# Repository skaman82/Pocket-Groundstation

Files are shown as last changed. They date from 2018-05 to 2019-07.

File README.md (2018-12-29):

# Pocket-Groundstation
The Pocket-Groundstation is a mini ground station that will accept any Fatshark module.</br> 
<strong>Project updates</strong> > https://github.com/skaman82/Pocket-Groundstation/blob/master/updates.md

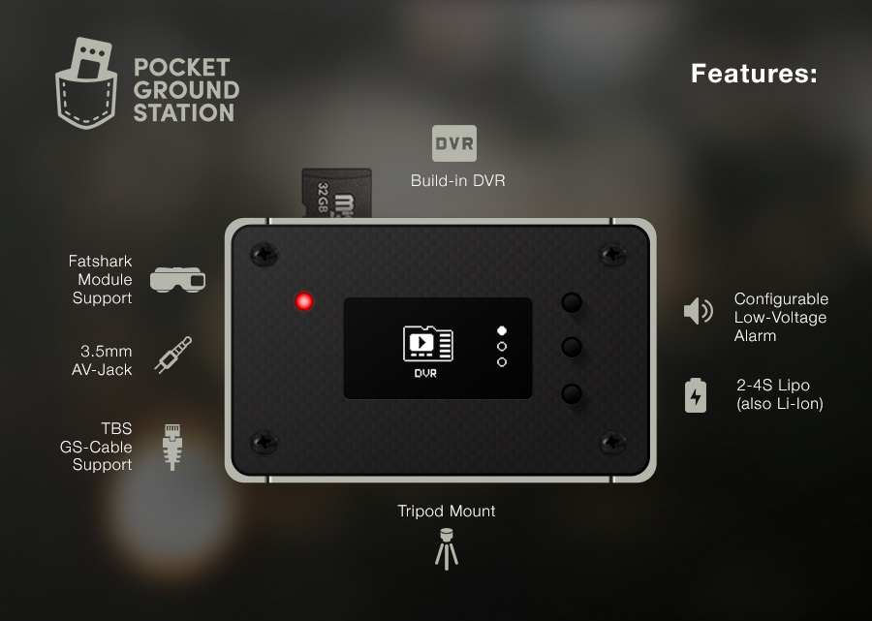
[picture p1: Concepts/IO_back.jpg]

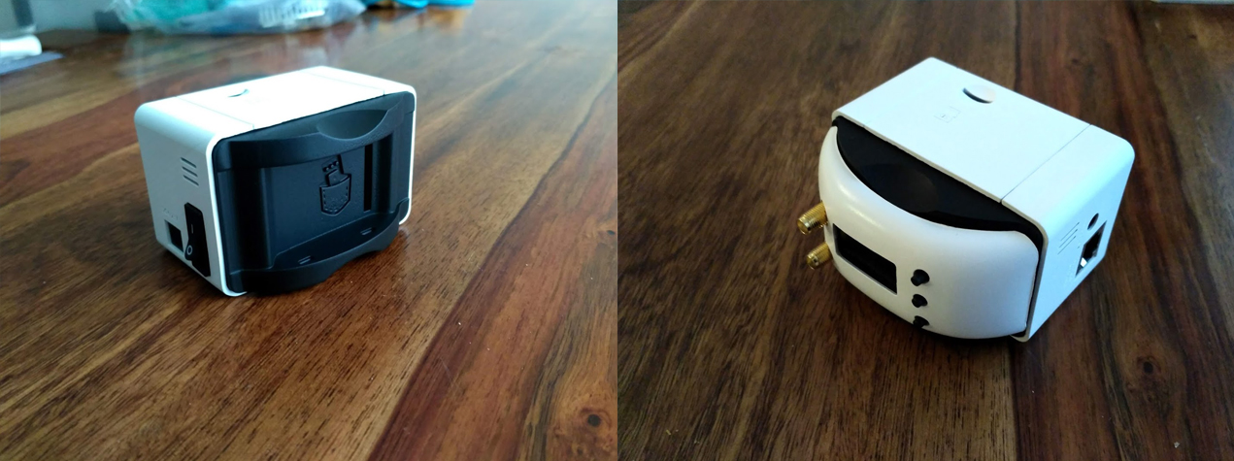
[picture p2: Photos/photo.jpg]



<b>Features:</b></br>
• takes 2S to 4S voltage</br>
• 3,5mm AV output</br>
• RJ45 output for power+AV (only one wire to goggles) - constant 8V output on any power source </br>
• Powerswitch</br>
• Build-in DVR</br>
• Automatical switching between DVR output (to adjust settings or review footage) or direct module output</br>
• Low-voltage alarm and cell autodetection (adjustable via OLED, so it can work with lipo or li-ion batteries)</br>
• DRV-control via OLED (Eachine Pro DVR)</br>
• RSSI/Channel-information and DVR-Autostart (only with True-D module with 3.7D firmware)</br>
</br>

If you want to join the project or contribute, you are very welcome to do so!</br></br>

<b>Parts:</b></br>
• 3D-Printed Parts </br>
or order them here: </br>
https://www.shapeways.com/product/CZG7FD8B4/pocketgroundstation-module-insert</br>
https://www.shapeways.com/product/DPKJJELEF/pocketgroundstation-case-side-cover</br>
https://www.shapeways.com/product/GCXG232QY/pocketgroundstation-case</br>
</br>
</br>
• PCBs (you can order them with the provided Gerber files in the PCB Folder at http://jlcpcb.com or other vendors) </br>
• M3 inserts (https://de.aliexpress.com/item/100-teile-los-messingeinsatz-M2-M2-5-M3-Durch-gewinde-messing-gewindebuchse-r-ndelmuttern-f-r/32840519444.html) </br>
• Tripod 1/4" Insert: (https://de.aliexpress.com/item/20Pcs-M3-M4-M5-M6-M8-Zinc-Plated-Carbon-Steel-Knurled-Nuts-Rivnut-Flat-Head-Threaded/32812028855.html)</br>
• Eachine PRO DVR </br>
• Arduino Pro Mini (https://de.aliexpress.com/item/1PCS-new-version-1pcs-ATMEGA328P-Pro-Mini-328-Mini-ATMEGA328-5V-16MHz-for-arduino/32830465958.html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)</br>
• 5V Buzzer</br>
• 3-35V to 1.2-30V Step up/down (https://de.aliexpress.com/item/DC-DC-Auto-Boost-Buck-Step-Up-Step-Down-Converter-Module-Solar-Voltage-LM2577-Module/32829391285.html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)</br>
• DC 5.5x2.5 PCB socket (https://de.aliexpress.com/item/10pcs-DC-005-Black-DC-Power-Jack-Socket-Connector-DC005-5-5-2-1mm-2-1/32361314769.html)</br>
• 3.5mm PCB socket (PJ-320D) (https://de.aliexpress.com/item/10pcs-lot-3-5-headphone-jack-audio-jack-PJ-320D-4-pin-SMD-MP3-Accessories-PJ320D/32439357849.html)</br>
• RJ45 PCB socket (RJ45 MOLEX 0446200002/RJ45 MOLEX 0446200001)</br>
• I2C OLED Display 1.3" (https://de.aliexpress.com/item/1-3-Inch-1-3-White-OLED-LCD-4PIN-Display-Module-IIC-I2C-Interface-128x64-for/32837066822.html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)</br>
• PWM video switch (https://de.aliexpress.com/item/2015-Mini-2-Ways-Video-Switcher-Module-2-Channels-Video-Switch-Unit-for-FPV/32552115472.html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)</br>
• Diode (SMD S1A)</br>
• Resistors 1206 (4.7K / 18K / 220 Ohm)</br>
• Red 3mm LED</br>
• Tactile buttons (3x) (https://de.aliexpress.com/item/100-st-cke-6-6-7mm-Licht-touch-schalter-DIP4-ON-OFF-Tactile-Push-button-micro/32846526815.html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)</br>
• Power switch (https://de.aliexpress.com/item/10Pcs-AC-125V-12A-250V-10A-SPST-2-Pin-2-Position-Mini-Marine-Boat-Switches-Rocker/32830066263.html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)</br>
• 5V 2A BEC (Diatone)</br>
• RJ45 TBS Tango Cable </br>
• Optional: 3.5mm AV Cable</br>
• Optional: Capacitator (470uF 25V)</br>

# The Build
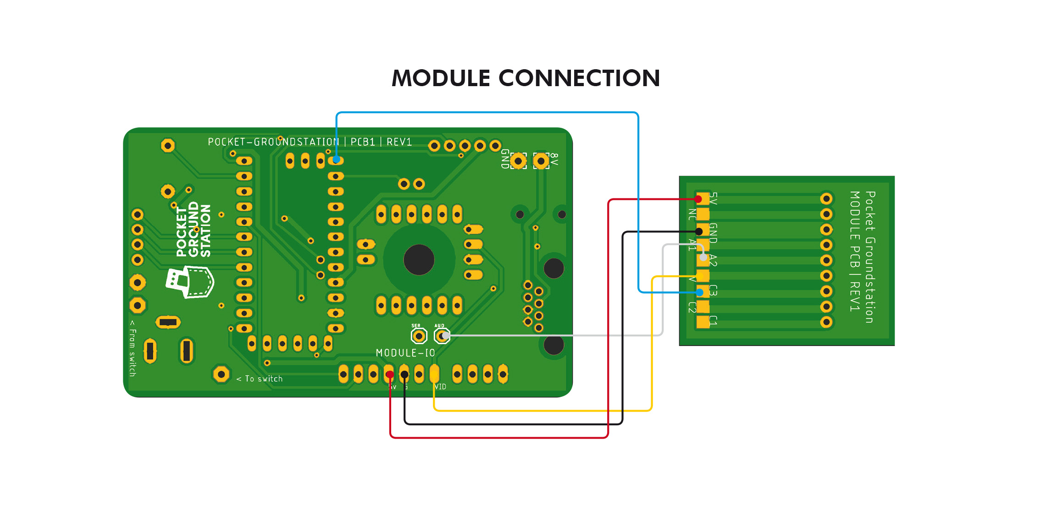
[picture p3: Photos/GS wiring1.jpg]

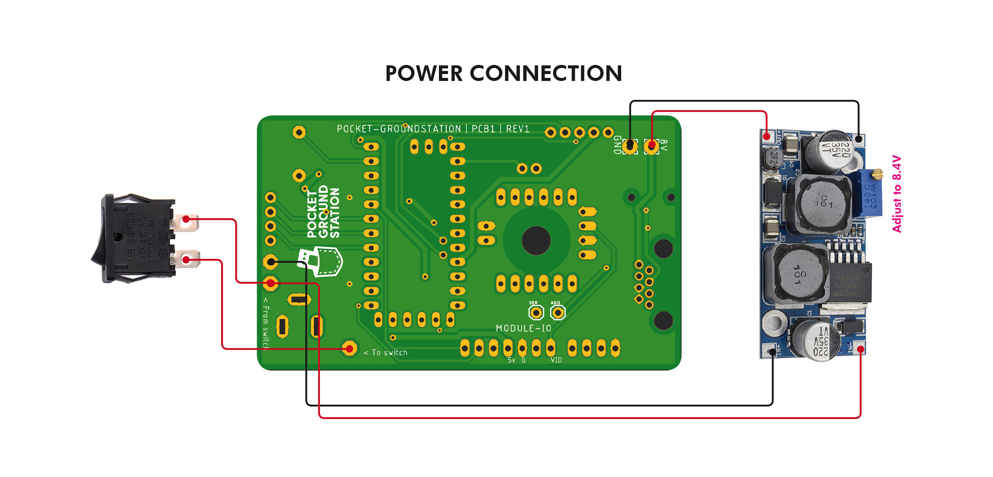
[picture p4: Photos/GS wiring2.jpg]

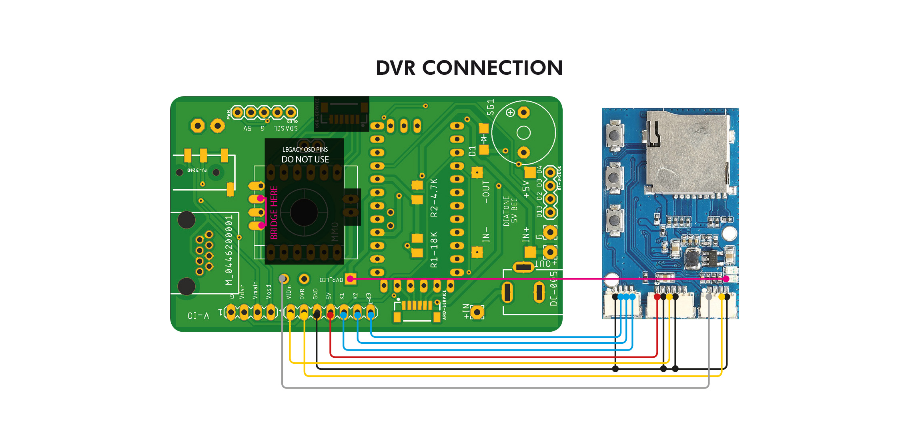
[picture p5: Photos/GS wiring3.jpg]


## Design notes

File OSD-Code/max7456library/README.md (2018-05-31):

# MAX7456
A library for interfacing with MAX7456 OSD chip originally created by people at http://theboredengineers.com/2012/12/a-max7456-library-for-arduino/.

This library should be compatible with Arduino IDE 1.6.6.

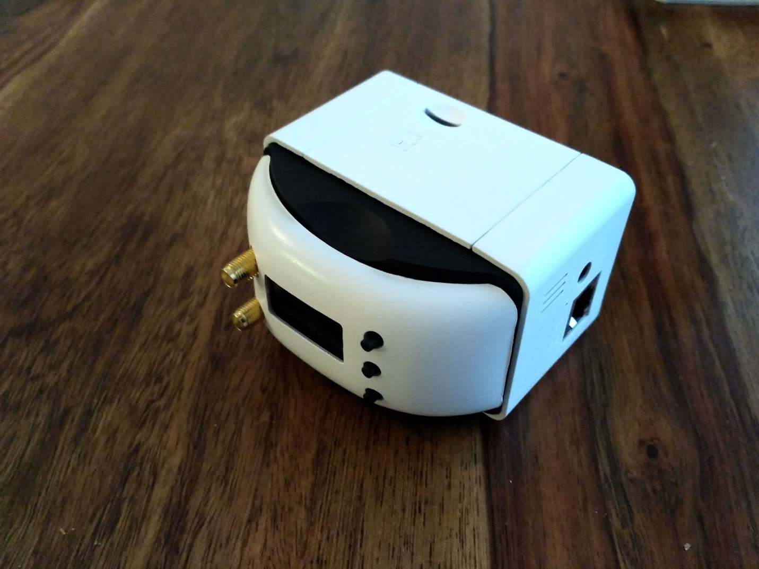
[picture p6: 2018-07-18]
Photos/IMG_20180714_202903_HDR.jpg

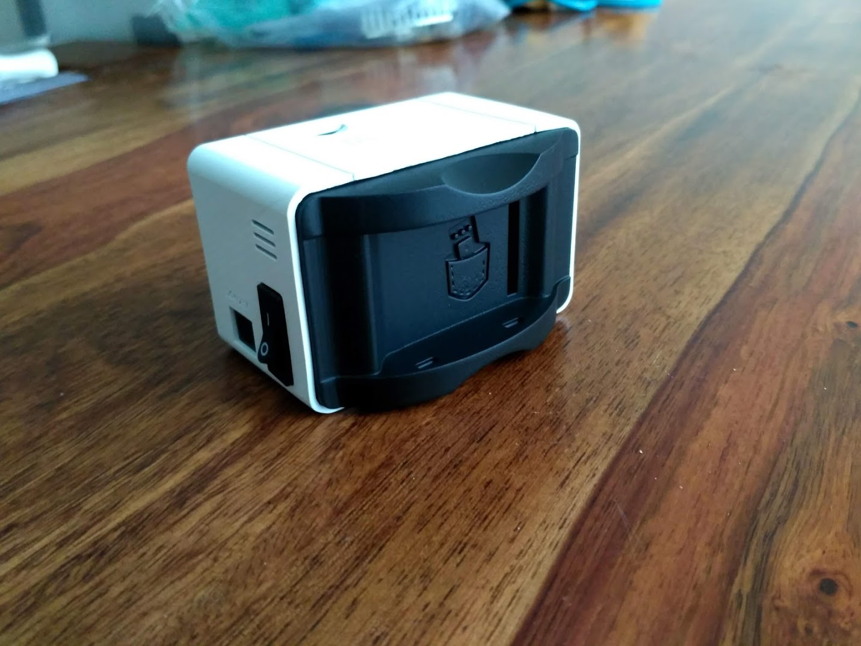
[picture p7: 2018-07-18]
Photos/IMG_20180714_121051_HDR.jpg

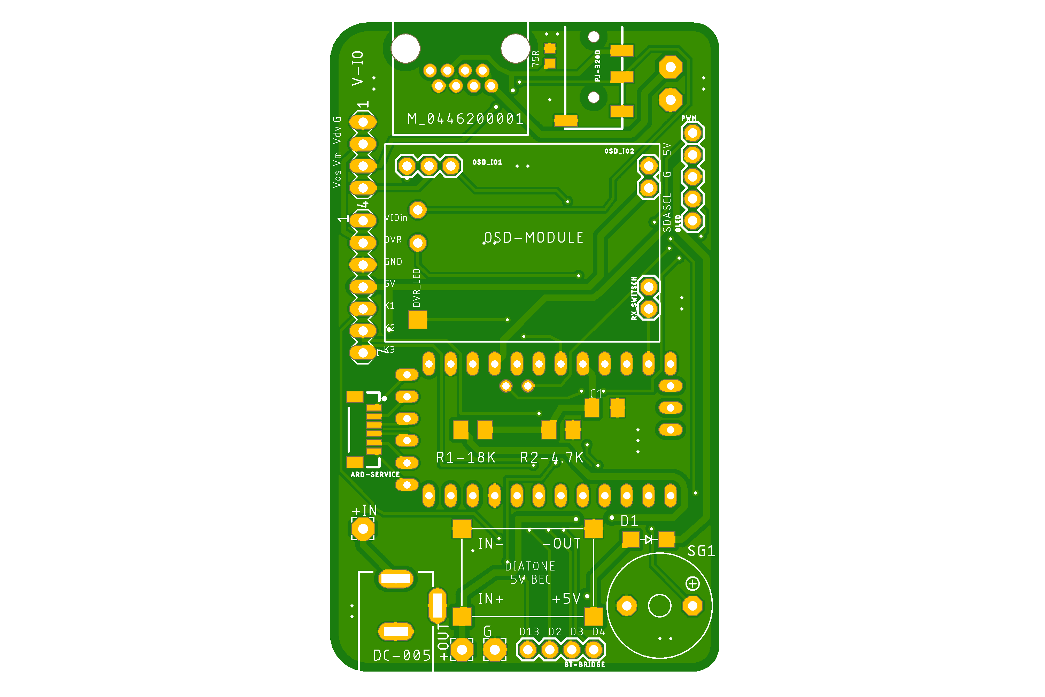
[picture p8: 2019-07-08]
PCB Files/Gerber Files/PCB 1_top.png

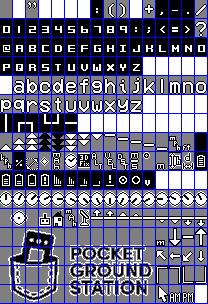
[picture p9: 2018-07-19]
OSD-Code/OSD fonts/pocketgroundstation-font.png

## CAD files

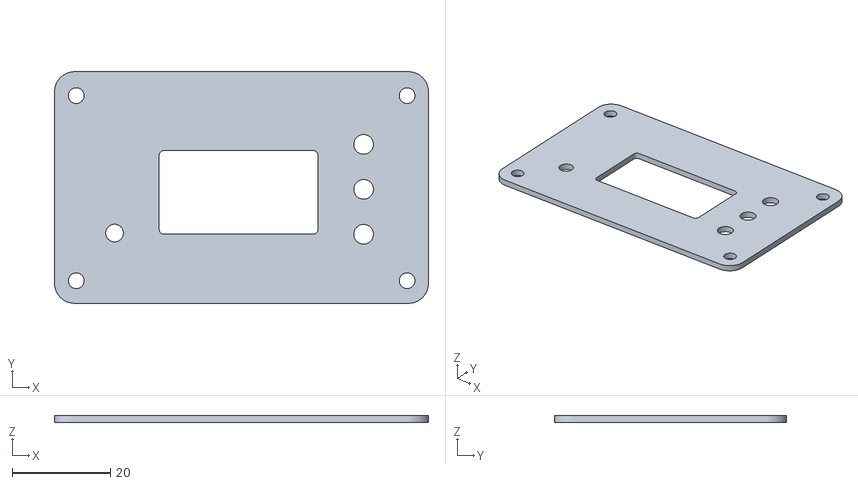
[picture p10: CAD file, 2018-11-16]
3D files/STLs/case cover plate 1,5mm_fixed.stl
76.0 x 47.1 x 1.50

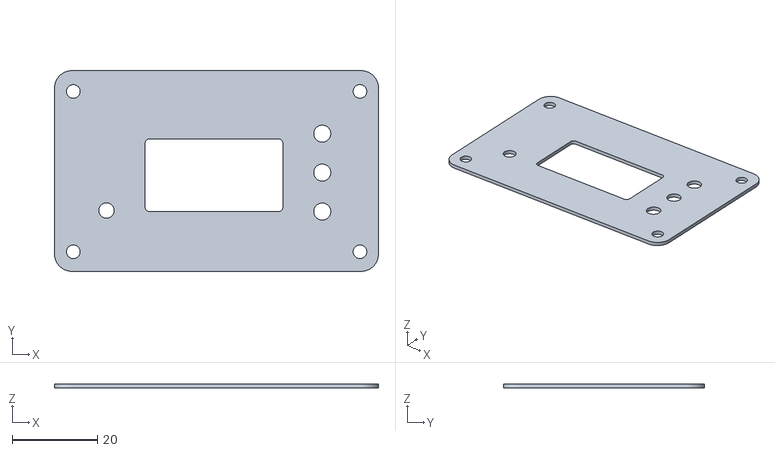
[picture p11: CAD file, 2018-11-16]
3D files/STLs/case cover plate 1,0mm_fixed.stl
76.0 x 47.1 x 1.00

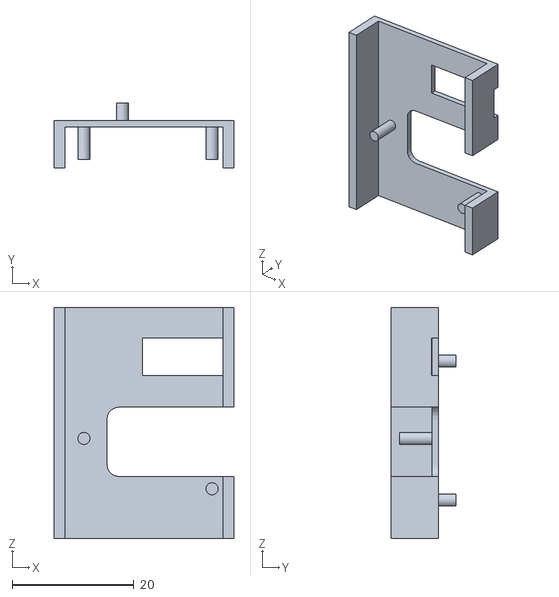
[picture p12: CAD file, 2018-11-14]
3D files/STLs/CE3_DVR adapter_scaled_fixed.stl
29.6 x 10.8 x 38.0

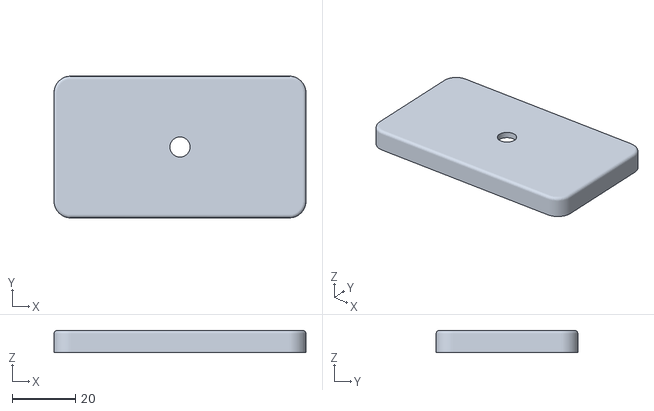
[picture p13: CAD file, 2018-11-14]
3D files/STLs/Magnet stand_fixed.stl
80.0 x 45.0 x 7.00

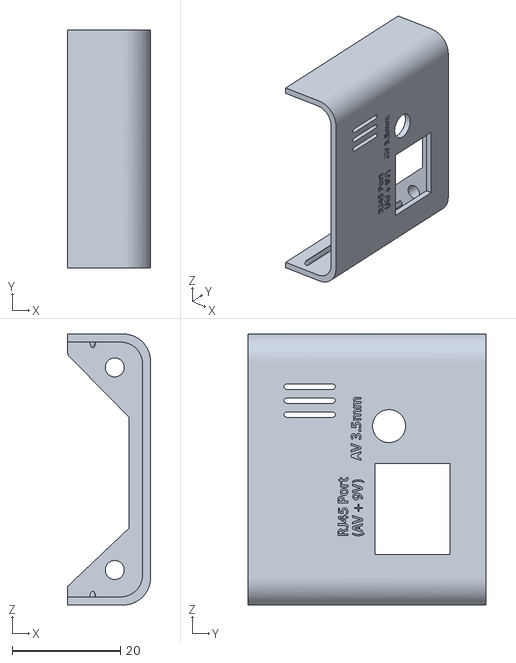
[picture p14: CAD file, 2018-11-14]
3D files/STLs/CE3_Side_left_scaled_fixed.stl
15.3 x 44.0 x 50.0

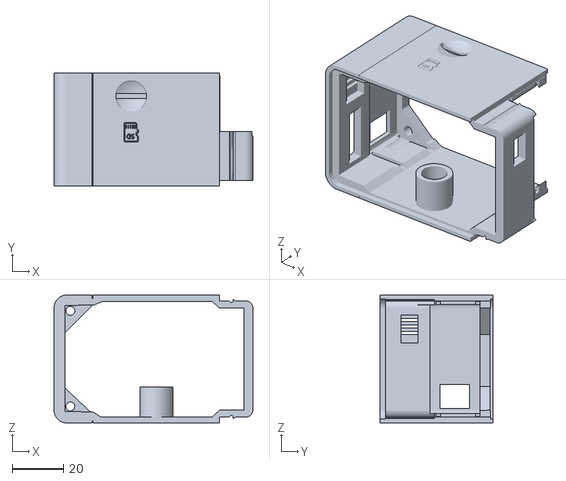
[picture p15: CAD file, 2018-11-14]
3D files/STLs/CE3_Case_scaled_fixed.stl
77.8 x 44.0 x 50.0

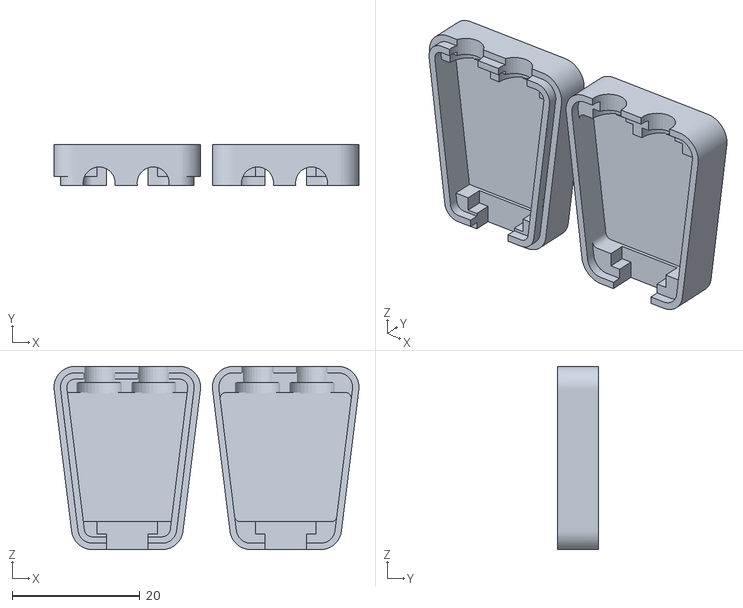
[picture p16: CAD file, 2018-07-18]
3D files/STLs/Cover_cable_fixed.stl
47.7 x 6.39 x 28.7

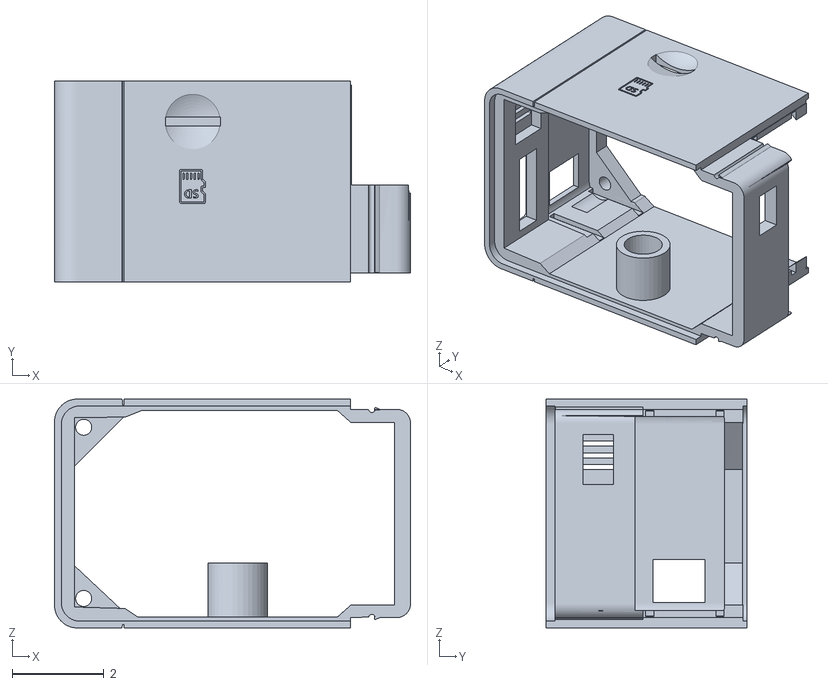
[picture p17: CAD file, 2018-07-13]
3D files/STLs/Case_fixed.stl
7.78 x 4.40 x 5.00

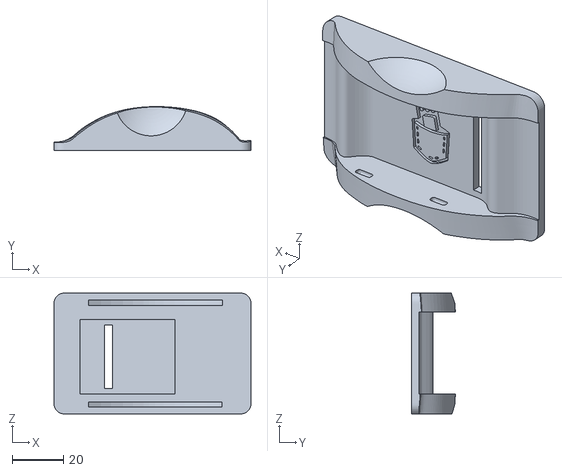
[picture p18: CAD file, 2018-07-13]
3D files/STLs/Module insert v3_fixed.stl
76.6 x 17.0 x 47.0

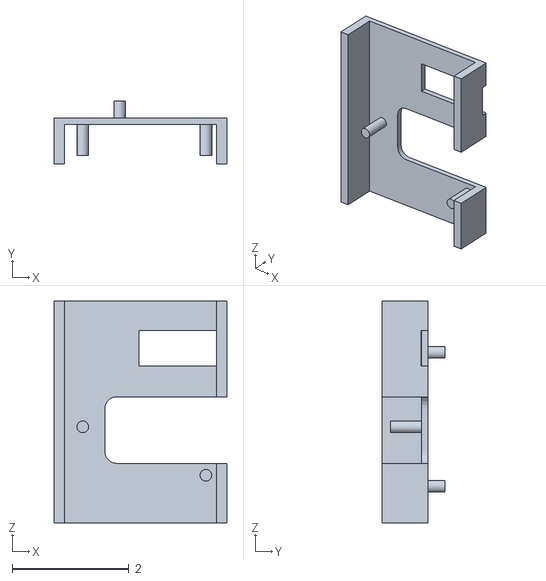
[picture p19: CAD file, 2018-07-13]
3D files/STLs/DVR adapter_fixed.stl
2.96 x 1.08 x 3.80

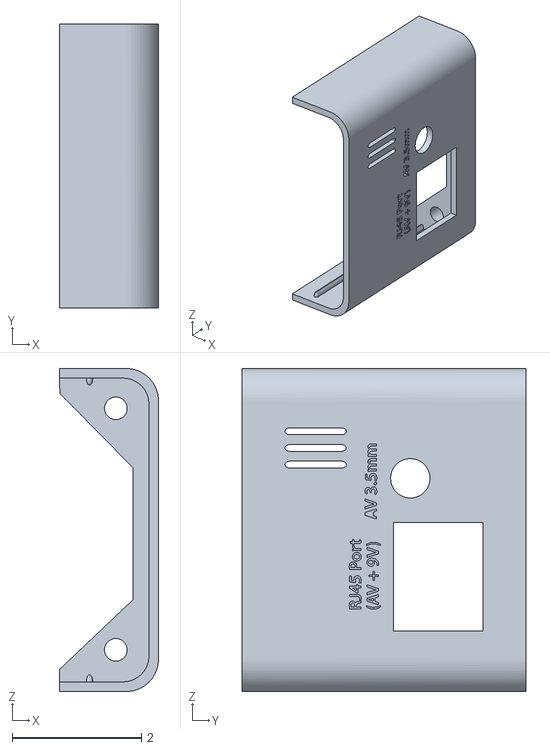
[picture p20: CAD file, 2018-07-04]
3D files/STLs/Side_left_fixed.stl
1.53 x 4.40 x 5.00

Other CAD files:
3D files/Case Cover DXF/case-cover plate.dxf
3D files/Cinema4D files/side left.dxf
3D files/Cinema4D files/module insert v3.dxf
3D files/Cinema4D files/case3.dxf

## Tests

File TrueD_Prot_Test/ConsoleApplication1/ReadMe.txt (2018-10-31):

========================================================================
    KONSOLENANWENDUNG: ConsoleApplication1-Projektübersicht
========================================================================

Diese ConsoleApplication1-Anwendung wurde vom Anwendungs-Assistenten für Sie erstellt.

Diese Datei bietet eine Übersicht über den Inhalt der einzelnen Dateien, aus
denen Ihre ConsoleApplication1-Anwendung besteht.

ConsoleApplication1.vcxproj
    Dies ist die Hauptprojektdatei für VC++-Projekte, die mit dem Anwendungs-Assistenten generiert werden. Sie enthält Informationen über die Version von Visual C++, mit der die Datei generiert wurde, sowie über die Plattformen, Konfigurationen und Projektfunktionen, die im Anwendungs-Assistenten ausgewählt wurden.

ConsoleApplication1.vcxproj.filters
    Dies ist die Filterdatei für VC++-Projekte, die mithilfe eines Anwendungs-Assistenten erstellt werden. Sie enthält Informationen über die Zuordnung zwischen den Dateien im Projekt und den Filtern. Diese Zuordnung wird in der IDE zur Darstellung der Gruppierung von Dateien mit ähnlichen Erweiterungen unter einem bestimmten Knoten verwendet (z. B. sind CPP-Dateien dem Filter "Quelldateien" zugeordnet).

ConsoleApplication1.cpp
    Dies ist die Hauptquelldatei der Anwendung.

/////////////////////////////////////////////////////////////////////////////
Andere Standarddateien:

StdAfx.h, StdAfx.cpp
    Mit diesen Dateien werden eine vorkompilierte Headerdatei (PCH) mit dem Namen ConsoleApplication1.pch und eine vorkompilierte Typendatei mit dem Namen StdAfx.obj erstellt.

/////////////////////////////////////////////////////////////////////////////
Weitere Hinweise:

Der Anwendungs-Assistent weist Sie mit "TODO:"-Kommentaren auf Teile des
Quellcodes hin, die Sie ergänzen oder anpassen sollten.

/////////////////////////////////////////////////////////////////////////////

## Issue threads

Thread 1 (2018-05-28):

Add voltage readout and buzzer warning + display on OLED

skaman82, 2018-05-28:

skaman82, 2018-06-05:
done

Closed 2018-06-05.

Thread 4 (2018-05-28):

DVR control in the OLED menu system

skaman82, 2018-05-28:

skaman82, 2018-06-06:
Menu structure
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

skaman82, 2018-06-06:
some graphics
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

skaman82, 2018-06-06:
@tavdog I've heard that you'd like to join our little project. Feel free to add some code any time :)

tavdog, 2018-06-12:
alright, lemme just do a little git refresher and I'll try to contribute.

skaman82, 2018-06-12:
@tavdog great!

skaman82, 2018-06-21:
done!

Closed 2018-06-21.

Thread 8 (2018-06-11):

Make battery indicator icon dynamically (OLED+OSD)

skaman82, 2018-06-11:
100% should be 4.2v and 0% whatever is set as voltage alarm.
We basically need a battery_health status instead of the blinkosd parameter to adjust the battery icon on OSD and OLED. Like battery_health

battery_health = 4 > 100%
battery_health = 3 > 75%
battery_health = 2 > 50%
battery_health = 1 > 25%
battery_health = 0 > 0% > voltage alarm (buzzer) > OSD icon is blinking

Closed 2018-06-15.

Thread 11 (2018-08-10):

Find a new OSD solution

skaman82, 2018-08-10:
THE MAX Chip seems not right for the job because it needs a perfect video to display the OSD. See: https://github.com/skaman82/Pocket-Groundstation/blob/master/updates.md

sheaivey, 2018-10-27:
Getting solid OSD on transmitted video feed is very difficult. LM1881 has the same issues in that regard as the MAX chips. We use the EL1883 which is a 3v i/o variant of the LM1881 in the La Forge FPV v4 module. But it also has the same issues with poor video sync pulses.
The only way around the sync issues would be to lock onto the sync pulses (PAL/NTSC) and asume the timing never changes and bang out the OSD out via an internal clock. Not an easy task to accomplish.

Aside from the sync issues the max chip offers a lot of features to offload the video generation from the main microcontroller. The LM1881 would require you to generate the video signal from a microcontroller usually done by bitbanging or using the SPI buffer.

Hopefully this helps in in some way with picking a OSD direction by explaining some of the tradeoffs.

skaman82, 2018-10-27:
@sheaivey yes thanks - I've looked into the LM1881 Solution and tried some different approaches - it's would be flyable because the "blue screen" is not there anymore compared to the MAX Chip. But I decided to drop the OSD feature because of poor sync performance.

sheaivey, 2018-10-27:
If the overlay OSD is an issue there is another option you could go with which is mirroring the OLED on a B&W video (not an overlay but generating your own video). This is really easy to accomplish and only requires 2 resistors and a transistor to switch the video source. You could have it switch over to the B&W in the goggles when the user presses a button and return to the video feed after no interaction has happened for 5 seconds. Just throwing ideas out there to consider.

skaman82, 2018-10-27:
Thanks, I thought of that. But I think im my case the most valuable information is the battery voltage and (if I solve this) the RSSI information and both values should be always visible on screen as an overlay. Displaying the OLED info would work only when you are not flying an you have to get to the buttons on the ground-station first

wx4cb, 2018-10-28:
Why not just have a locally generated sync pulse and just switch to it when needed. The problem with the dockking for me is that there are some elements u cant remove so they get in the way of the osd i have on the aircraft

skaman82, 2018-10-28:
@wx4cb I have actually have no clue how to get this done :D This is what the max chip does when the video rssi gets a bit low (sync loss/flicker + grey background) https://youtu.be/zhLGqg2VBxQ - the LM1881 behaves basically the same (sync loss/flicker but without the grey background).

JyeSmith, 2018-10-28:
@skaman82 while the rest of the community is developing an OSD, I am not convinced it is a useful feature.  Displaying VTx RSSI isnt really useful, unlike radio link RSSI.  Regardless of the VTx RSSI value we will still fly if the image is acceptable.

It may also become a redundant feature since most new VRx modules being released will have an OSD.

But if you are going to continue with an OSD you might like to checkout the work over at WPro58 if you haven't.

https://github.com/piodabro/WPro58

skaman82, 2018-10-29:
@JyeSmith yes, its not like it is a "killer feature" and I abandoned this feature for now but having some data displayed still seems useful to me. Like: seeing if the DVR is running and the battery status of the groundstation - rssi is just a bonus. If you are 10km out its nice to have the battery info. But again, you can just adjust the voltage alarm to go off a bit earlier...

B.T.W. - I tried the new True-D 2.4GHz module with its integrated OSD - it has the same sync issues I had encountered on my LM1881 test setups (OSD is flickering and then completely disappearing)

skaman82, 2019-01-05:
I am currently looking into a way to still use the MAX based OSD, but switch to direct RX feed on sync loss - not a 100% solution, but usable if it works

skaman82, 2019-01-05:
Ok, this looks promising: https://youtu.be/Wh2_j9sja44

Wired the LOS pin from the MAX chip to the VBAT1 pin on the minimosd micro to detect sync loss and controlling two LEDs with the CURR and RSSI pads. I think that we could switch to a direct videofeed from the RX during sync loss to prevent the grey screen blocking the image. Ordered some CD4066B switches to test.

fedorcomander, 2019-01-05:
You are most welcome ;)

skaman82, 2019-01-11:
some progress on OSD fallback in case of sync loss: https://www.youtube.com/watch?v=TMlkBO-3MI4&feature=youtu.be. Using 4066 for switching.

realhuno, 2019-08-26:
Hi, any news? I looking for something like this to make my capture the flag game for racing quads.
i need an osd and a groundstation to push in the team-points. red and blue team. The Flag State (R =red and B=blue)

my first idea was to use an minosd like here in your projekt...
https://www.youtube.com/watch?v=jcf5mTSx9RA

my second try with the internal OSD from the quad. This solution only works on betaflight and frsky telemetry. (i use the telemetry to change the pilot name for my points)
i only can use ppm values and they flickering ;-(

skaman82, 2019-08-30:
@realhuno I sadly cold't find a good solution for this (more a workaround) so I've just abandoned this topic until somebody has a better idea

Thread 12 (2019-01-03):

[Improvement] Missing Eagle Libs

StoneColdCrazy, 2019-01-03:
Hi, i take a closer look on youre eagle files and habe missing libs. (I plan to build and test it with an rapidFire Module, maybe the sync for the osd is cleaner ;) )

But Eagle is missing some custom libs:
> PCB 1D -> Arduino-clone / FPVTools
> PCB 2D -> diy-modules

Can you upload them also?
Makes it easyer to stay in sync

skaman82, 2019-01-03:
BTW. Rapidfire will not help with the sync issues

skaman82, 2019-01-03:
Uploaded

StoneColdCrazy, 2019-01-03:
Thank you, maybe i want to change some of your layouts, so it was better to have the missing libs...

Closed 2019-01-03.

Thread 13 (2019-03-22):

Channel Up and Down buttons

BluJ-FPV, 2019-03-22:
What would be required to add support for channel up and down buttons? The same as the fatsharks have? Some modules such as the clear view use these buttons for changing channels within a band.

skaman82, 2019-03-22:
One of the three pins required for that is used for serial communication with the true-d modules at the moment. I can imagine adding this but then you have to decide in-between serial support OR channel switching buttons before uploading the code to the arduino.

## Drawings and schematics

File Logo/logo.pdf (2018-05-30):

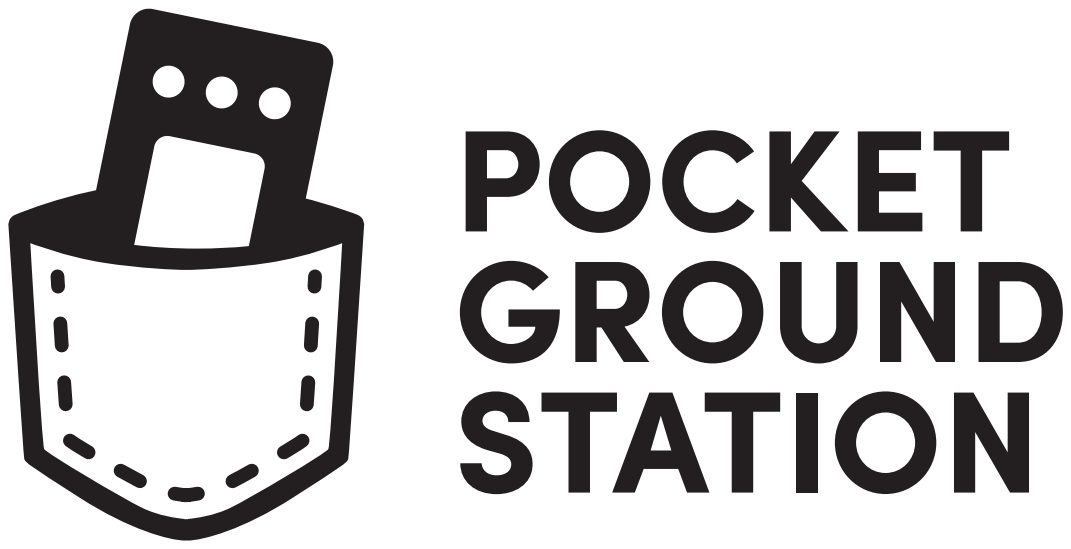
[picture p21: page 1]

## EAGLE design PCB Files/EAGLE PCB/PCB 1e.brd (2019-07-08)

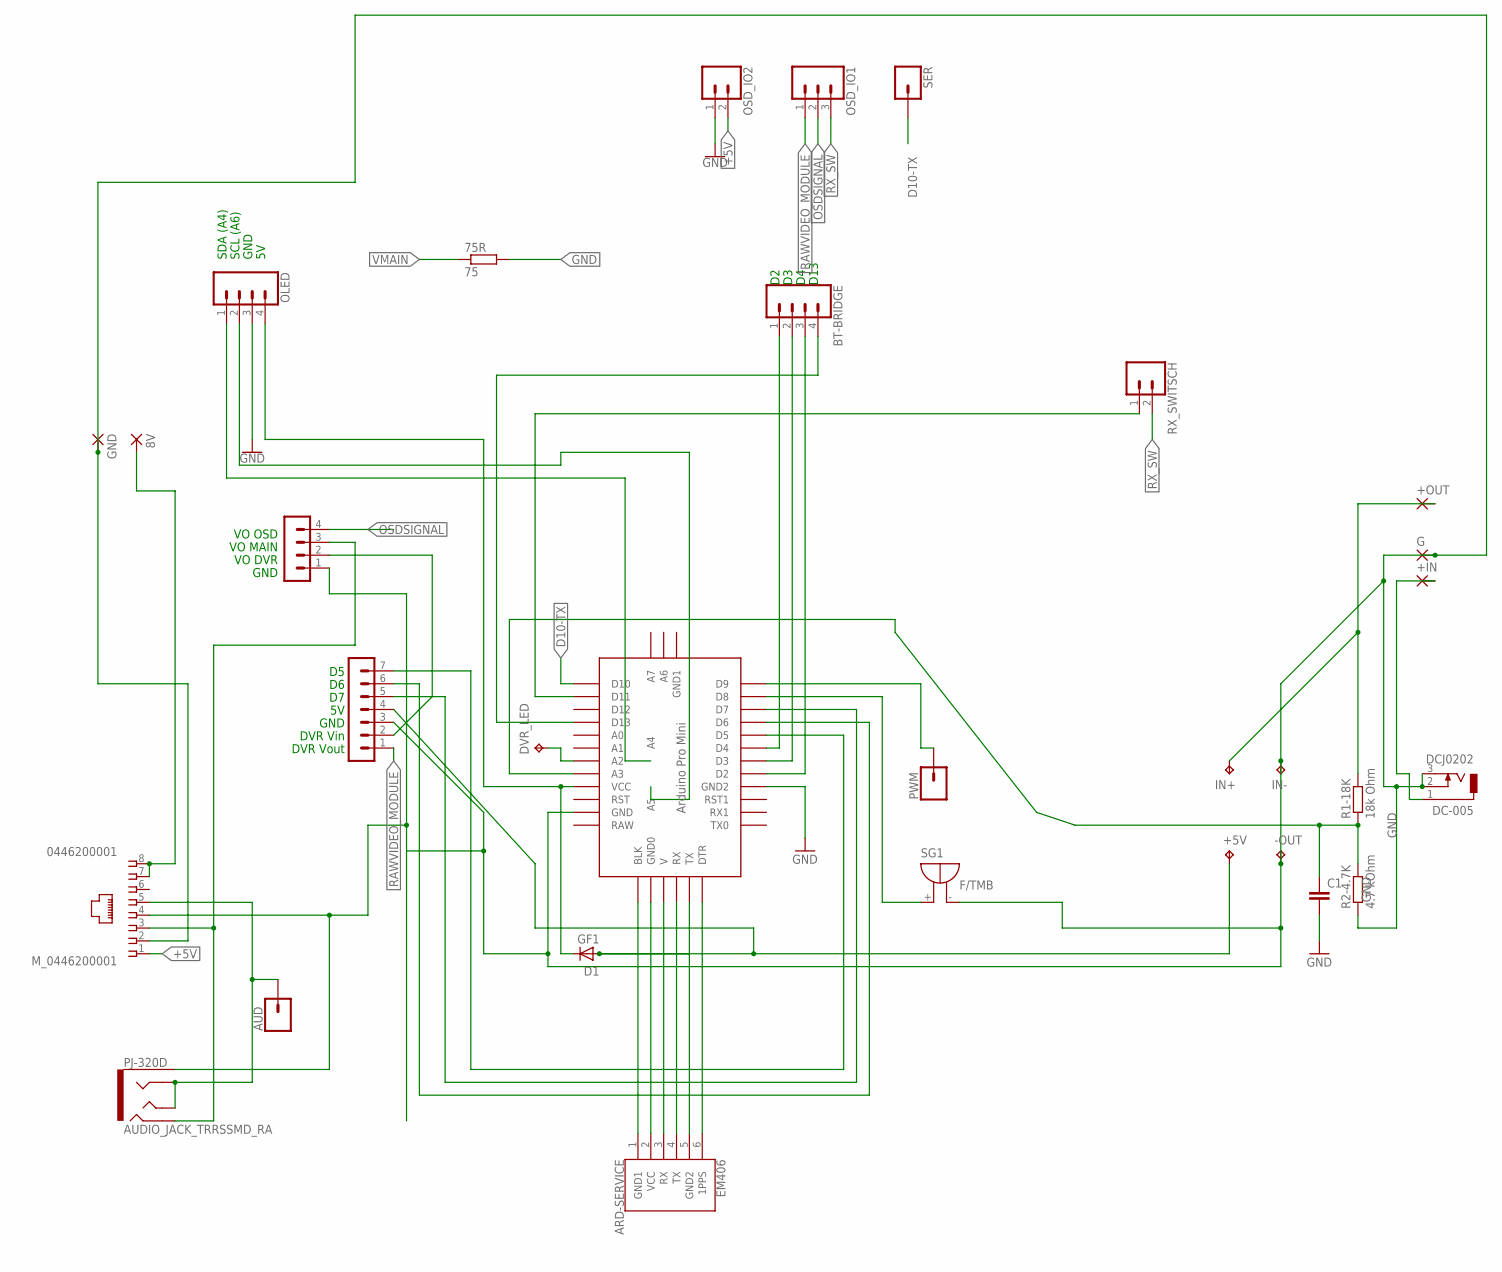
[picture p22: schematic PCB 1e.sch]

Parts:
8V: 2,54/1,1
75R: 75; R0603
+5V: TPTP20SQ; TP20SQ
+IN: 2,54/1,1
+OUT: 2,54/1,1
-OUT: TPTP20SQ; TP20SQ
ARD-SERVICE: EM406; 1X06-1MM
AUD: CONN_01; 1X01
BT-BRIDGE: CONN_04; 1X04
C1: C-EUC1206K; C1206K
D1: GF1; SMA-DO214AC
DC-005: DCJ0202
DVR_LED: TPTP20SQ; TP20SQ
G: 2,54/1,1
GND: 2,54/1,1
IN+: TPTP20SQ; TP20SQ
IN-: TPTP20SQ; TP20SQ
MODULE-IO: MA07-1
M_0446200001: 0446200001
OLED: CONN_04; 1X04
OSD_IO1: CONN_03; 1X03
OSD_IO2: CONN_02; 1X02
PJ-320D: AUDIO_JACK_TRRSSMD_RA; AUDIO_JACK_3.5MM_TRRS_SMD_RA
PWM: CONN_01; 1X01
R1-18K: 18k Ohm; M1206
R2-4.7K: 4.7 kOhm; M1206
RX_SWITSCH: CONN_02; 1X02
SER: CONN_01; 1X01
SG1: F/TMB
U$1: ABK-PRO-MINI
V-IO: MA04-1

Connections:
5VPROTECTED: D1.K (C), OLED.4, U$1.VCC
8V: 8V.1, M_0446200001.7, M_0446200001.8
+: +IN.1, DC-005.1
+5V: +5V.TP, D1.A, MODULE-IO.4, M_0446200001.1, OSD_IO2.2
AUDIO: AUD.1, M_0446200001.5, PJ-320D.RING1, PJ-320D.TIP
BUTTON1: BT-BRIDGE.3, U$1.D2
BUTTON2: BT-BRIDGE.2, U$1.D3
BUTTON3: BT-BRIDGE.1, U$1.D4
BUZZER: SG1.+, U$1.D8
D5: MODULE-IO.7, U$1.D5
D6: MODULE-IO.6, U$1.D6
D7: MODULE-IO.5, U$1.D7
D9PWM: PWM.1, U$1.D9
D10-TX: SER.1, U$1.D10
D11-RX: RX_SWITSCH.1, U$1.D11
DVRVIDEO-IN: MODULE-IO.2, V-IO.2
GND: 75R.2, -OUT.TP, C1.2, DC-005.2, DC-005.3, G.1, GND.1, IN-.TP, MODULE-IO.3, M_0446200001.2, M_0446200001.4, OLED.3, OSD_IO2.1, PJ-320D.EARTH, R2-4.7K.1, SG1.-, U$1.GND, U$1.GND1 (GND2), V-IO.1
LED: BT-BRIDGE.4, U$1.D13
unnamed: DVR_LED.TP, U$1.A1 (A2)
unnamed: ARD-SERVICE.1 (GND1), U$1.BLK
unnamed: ARD-SERVICE.2 (VCC), U$1.G (GND0)
unnamed: ARD-SERVICE.3 (RX), U$1.5V (V)
unnamed: ARD-SERVICE.5 (GND2), U$1.TX01 (TX)
unnamed: ARD-SERVICE.6 (1PPS), U$1.DTR
OSDSIGNAL: OSD_IO1.2, V-IO.4
RAWVIDEO_MODULE: MODULE-IO.1, OSD_IO1.1
RX_SW: OSD_IO1.3, RX_SWITSCH.2
SCL: OLED.2, U$1.A5
SDA: OLED.1, U$1.A4
V: ARD-SERVICE.4 (TX), U$1.RX01 (RX)
VCC: +OUT.1, IN+.TP, R1-18K.2
VMAIN: 75R.1, M_0446200001.3, PJ-320D.RING2, V-IO.3
VSENS: C1.1, R1-18K.1, R2-4.7K.2, U$1.A0 (A3)

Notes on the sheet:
VO OSD
VO MAIN
VO DVR
GND
DVR Vin
DVR Vout
SDA (A4)
SCL (A6)
D13

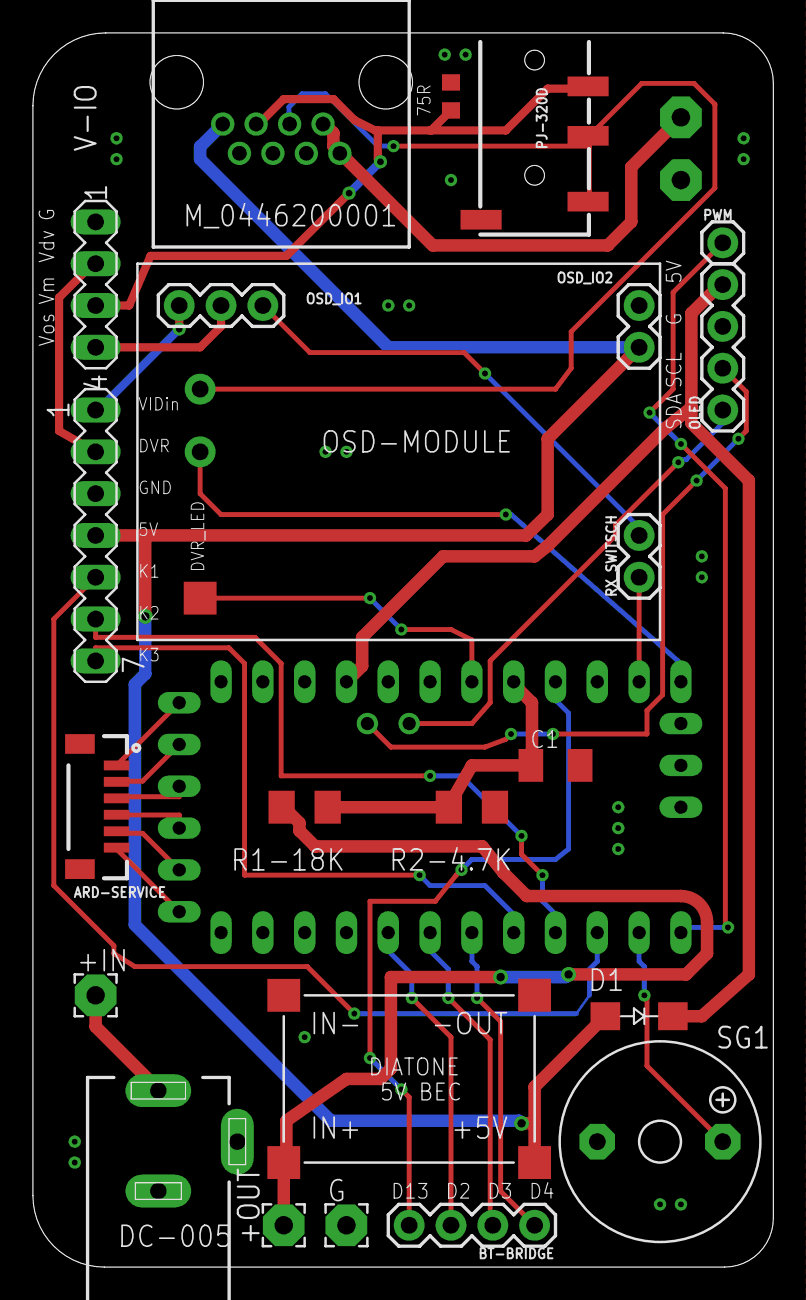
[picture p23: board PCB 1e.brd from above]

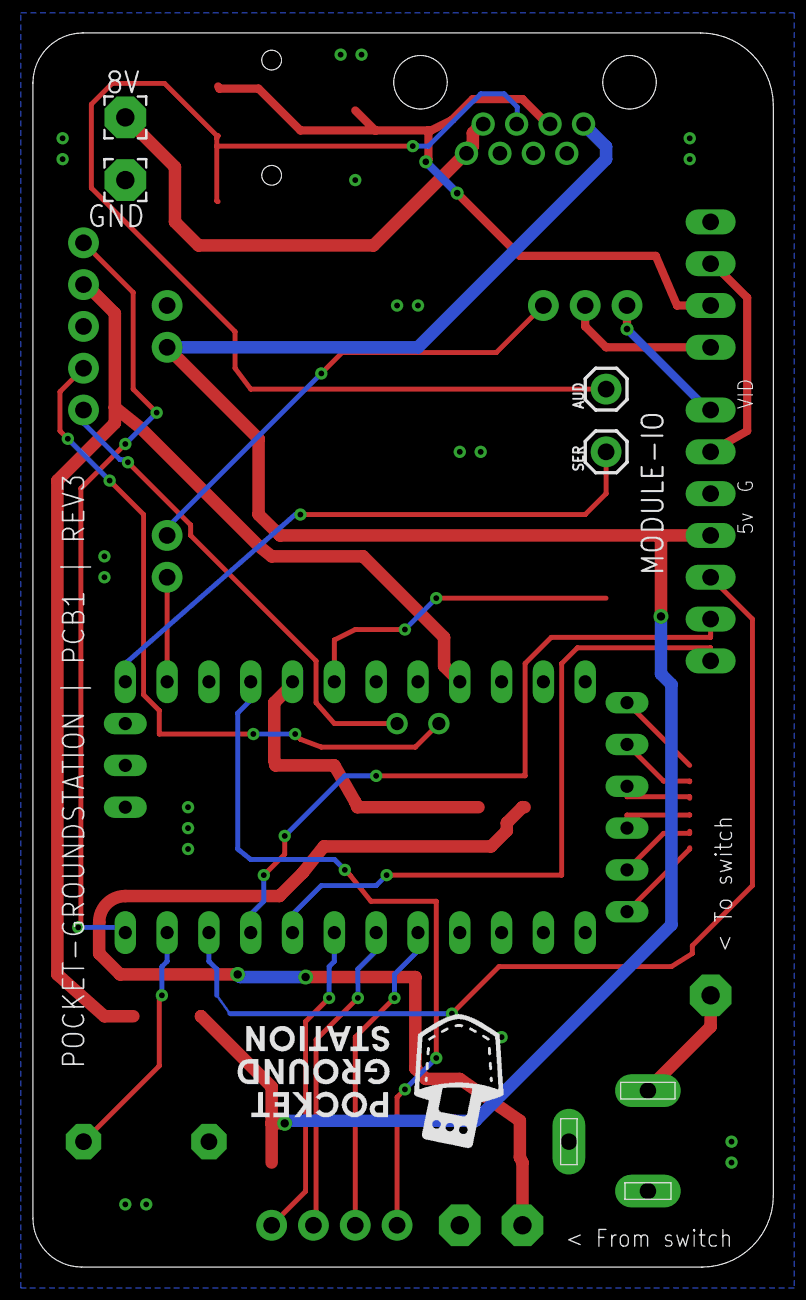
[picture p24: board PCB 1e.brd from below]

Board: 2 copper layers, 45.0 x 75.0 mm, 31 parts (4 on the bottom side), 33 nets.

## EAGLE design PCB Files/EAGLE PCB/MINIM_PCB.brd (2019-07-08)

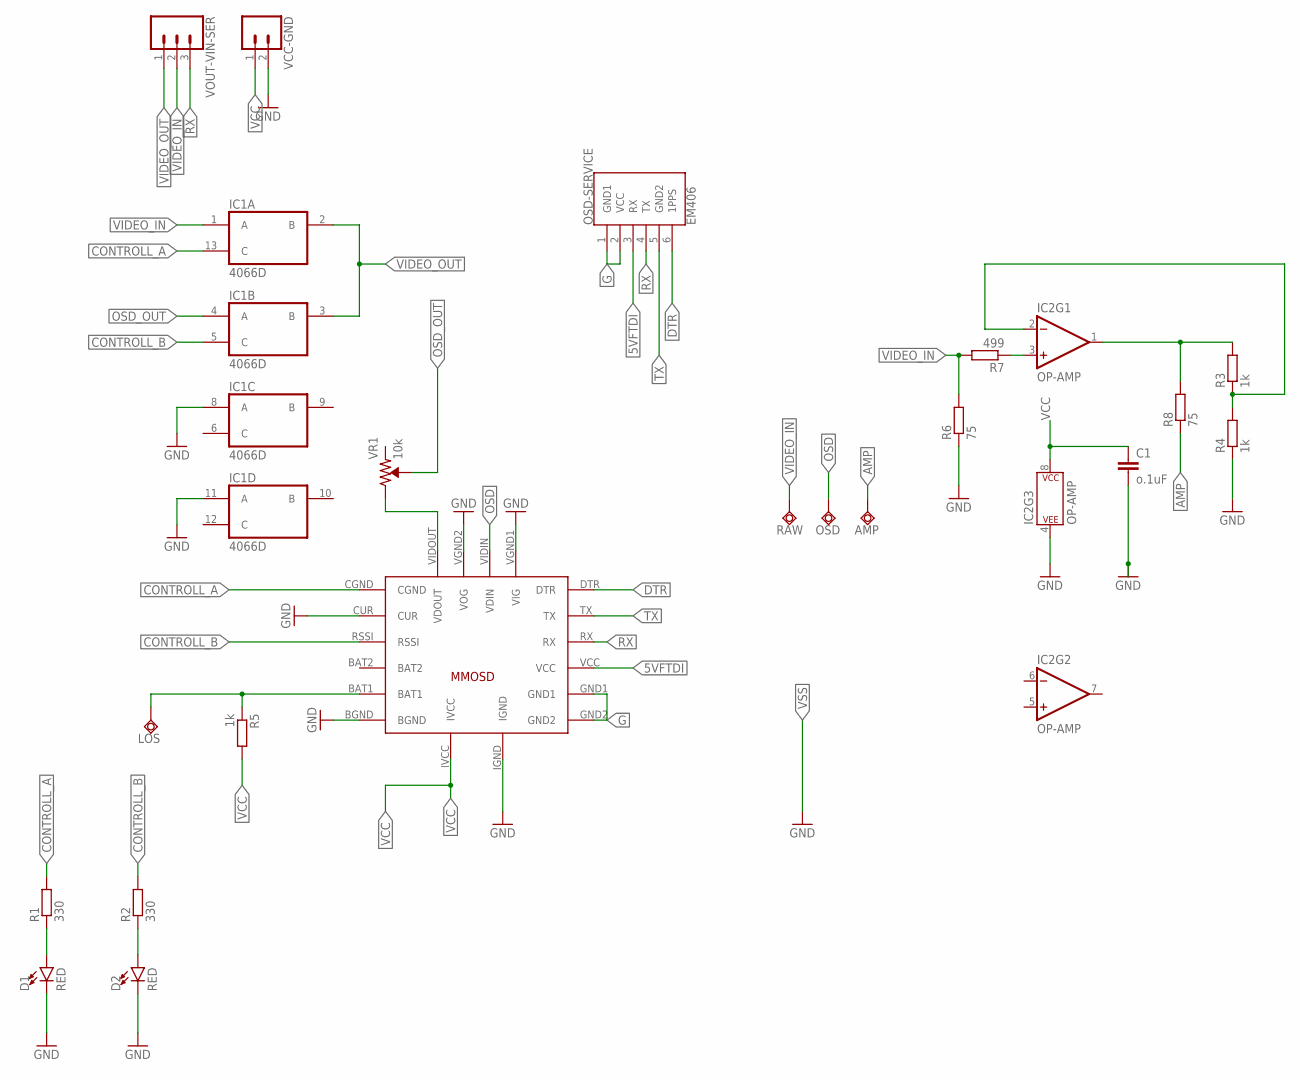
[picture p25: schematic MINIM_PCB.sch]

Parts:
AMP: TPSQTP13SQ; TP13SQ
C1: o.1uF; C0603K
D1, D2: RED; LED-1206
IC1: 4066D; SO14
IC2: OP-AMP; SO08
LOS: TPSQTP13SQ; TP13SQ
MINIMOSD: MICROMINIMOSDPWR; MMOSDNVDVID
OSD: TPSQTP13SQ; TP13SQ
OSD-SERVICE: EM406; 1X06-1MM
R1, R2: 330; R0603
R3, R4, R5: 1k; R0603
R6, R8: 75; R0603
R7: 499; R0603
RAW: TPSQTP13SQ; TP13SQ
VCC-GND: CONN_02; 1X02
VOUT-VIN-SER: CONN_03; 1X03
VR1: 10k; TRIMPOT-SMD-3MM-CLOSED

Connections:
5VFTDI: MINIMOSD.VCC, OSD-SERVICE.3 (RX)
75: IC2.1 (OUT), R3.2, R8.2
AMP: AMP.TP, R8.1
BAT2: MINIMOSD.BAT2
CONTROLL_A: IC1.13 (C), MINIMOSD.CGND, R1.2
CONTROLL_B: IC1.5 (C), MINIMOSD.RSSI, R2.2
DTR: MINIMOSD.DTR, OSD-SERVICE.6 (1PPS)
G: MINIMOSD.GND1, MINIMOSD.GND2, OSD-SERVICE.1 (GND1), OSD-SERVICE.2 (VCC)
GND: C1.2, D1.C, D2.C, IC1.8 (A), IC1.11 (A), IC2.4 (P$V-), MINIMOSD.BGND, MINIMOSD.CUR, MINIMOSD.IGND, MINIMOSD.VGND1 (VIG), MINIMOSD.VGND2 (VOG), R4.1, R6.1, VCC-GND.2
unnamed: D2.A, R2.1
unnamed: D1.A, R1.1
unnamed: LOS.TP, MINIMOSD.BAT1, R5.1
unnamed: IC2.2 (-IN), R3.1, R4.2
unnamed: MINIMOSD.VIDOUT (VDOUT), VR1.3 (CW)
OSD: MINIMOSD.VIDIN (VDIN), OSD.TP
OSD_OUT: IC1.4 (A), VR1.2 (WIPER)
RX: MINIMOSD.RX, OSD-SERVICE.4 (TX), VOUT-VIN-SER.3
TX: MINIMOSD.TX, OSD-SERVICE.5 (GND2)
VCC: C1.1, IC1.14 (VDD), IC2.8 (P$V+), MINIMOSD.IVCC, R5.2, VCC-GND.1
VIDEO_IN: IC1.1 (A), R6.2, R7.2, RAW.TP, VOUT-VIN-SER.2
VIDEO_OUT: IC1.2 (B), IC1.3 (B), VOUT-VIN-SER.1
VIDIN_AMP: IC2.3 (+IN), R7.1
VSS: IC1.7 (VSS)

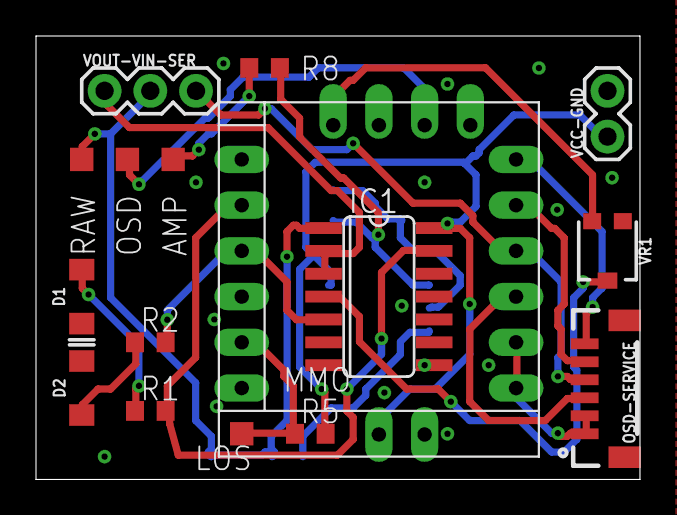
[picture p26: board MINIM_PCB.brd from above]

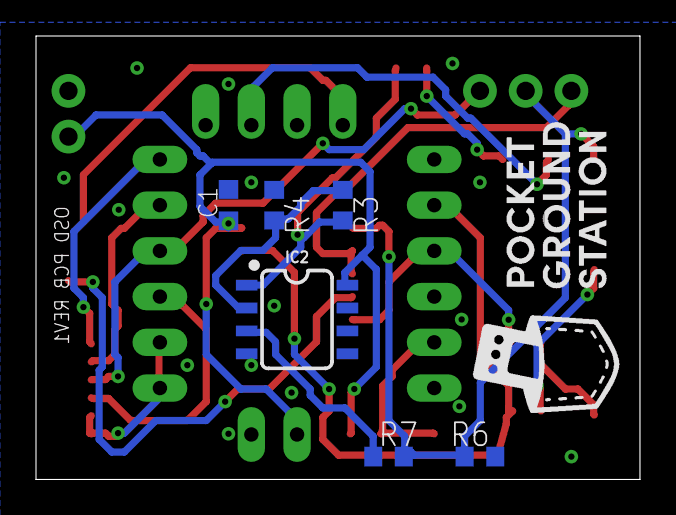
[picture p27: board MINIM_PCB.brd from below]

Board: 2 copper layers, 33.6 x 24.6 mm, 22 parts (6 on the bottom side), 21 nets.

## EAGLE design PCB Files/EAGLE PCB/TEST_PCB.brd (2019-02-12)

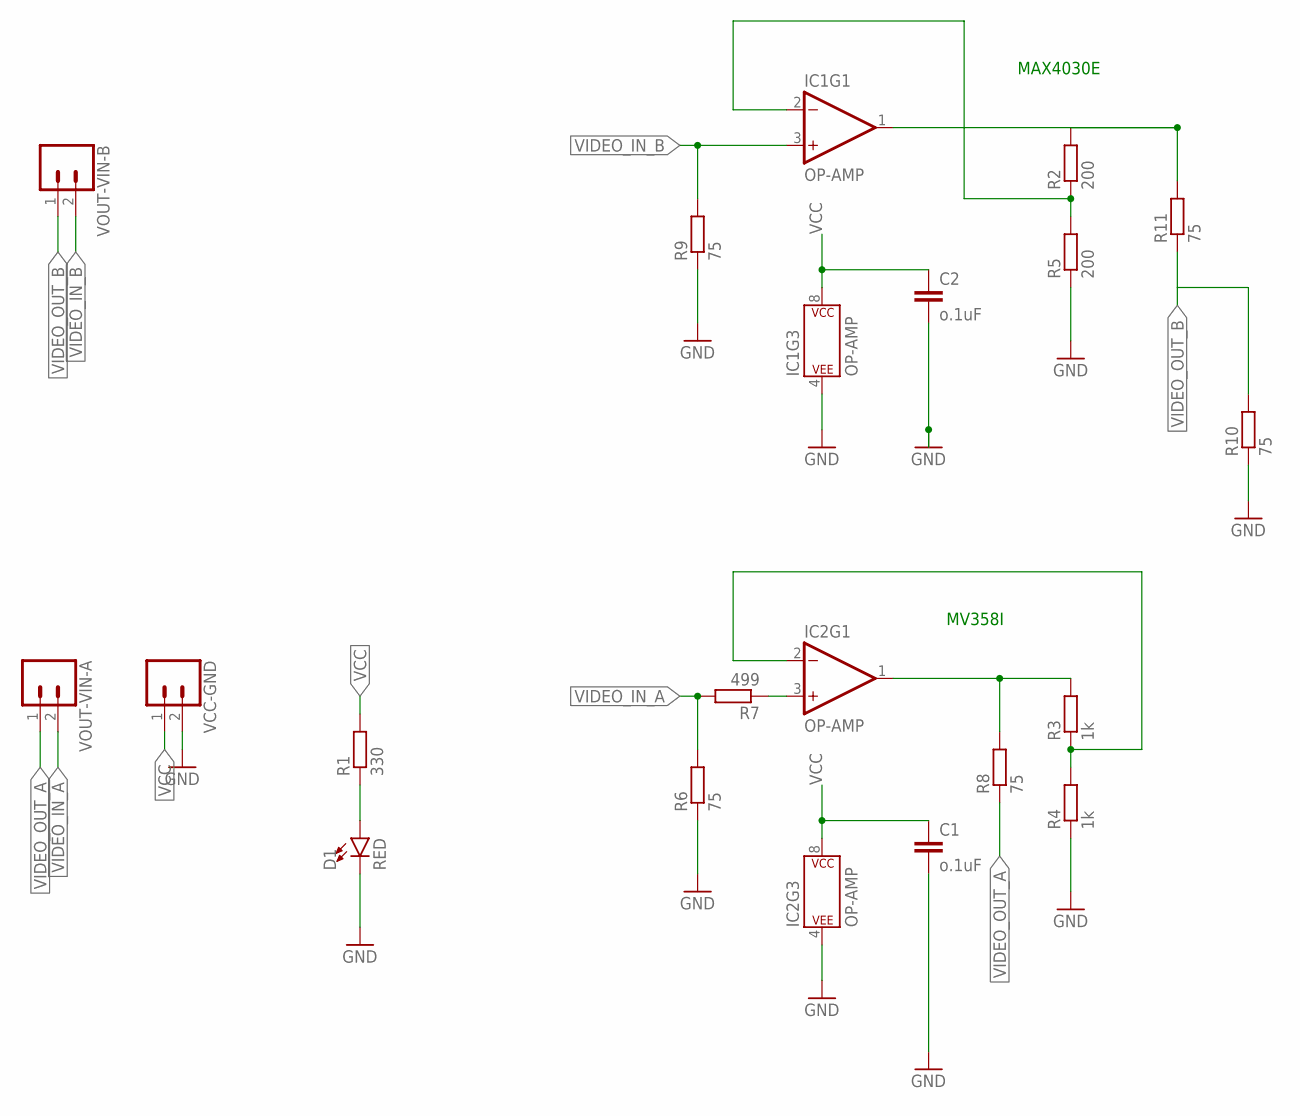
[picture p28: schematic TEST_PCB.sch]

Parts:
C1, C2: o.1uF; C0603K
D1: RED; LED-1206
IC1, IC2: OP-AMP; SO08
R1: 330; R0603
R2, R5: 200; R0603
R3, R4: 1k; R0603
R6, R8, R9, R10, R11: 75; R0603
R7: 499; R0603
VCC-GND: CONN_02; 1X02
VOUT-VIN-A: CONN_02; 1X02
VOUT-VIN-B: CONN_02; 1X02

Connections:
1: IC1.1 (OUT), R2.2, R11.2
75: IC2.1 (OUT), R3.2, R8.2
GND: C1.2, C2.2, D1.C, IC1.4 (P$V-), IC2.4 (P$V-), R4.1, R5.1, R6.1, R9.1, R10.1, VCC-GND.2
unnamed: IC1.2 (-IN), R2.1, R5.2
unnamed: D1.A, R1.1
unnamed: IC2.2 (-IN), R3.1, R4.2
unnamed: IC2.3 (+IN), R7.1
VCC: C1.1, C2.1, IC1.8 (P$V+), IC2.8 (P$V+), R1.2, VCC-GND.1
VIDEO_IN_A: R6.2, R7.2, VOUT-VIN-A.2
VIDEO_IN_B: IC1.3 (+IN), R9.2, VOUT-VIN-B.2
VIDEO_OUT_A: R8.1, VOUT-VIN-A.1
VIDEO_OUT_B: R10.2, R11.1, VOUT-VIN-B.1

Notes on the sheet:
MAX4030E
MV358I

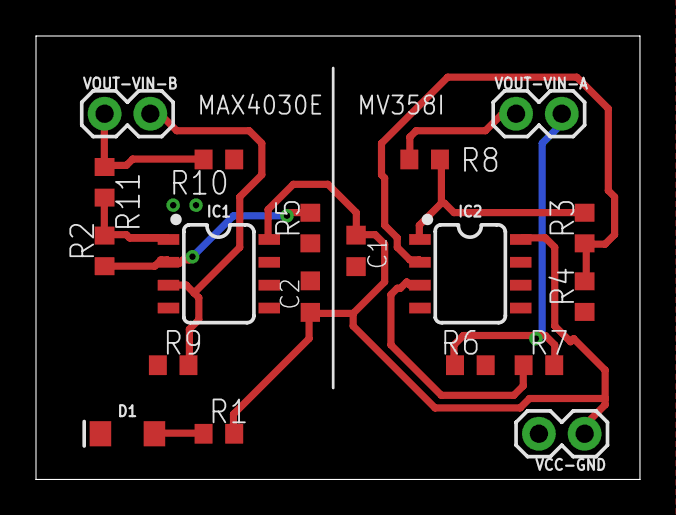
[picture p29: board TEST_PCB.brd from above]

Board: 2 copper layers, 33.6 x 24.6 mm, 19 parts (0 on the bottom side), 12 nets.

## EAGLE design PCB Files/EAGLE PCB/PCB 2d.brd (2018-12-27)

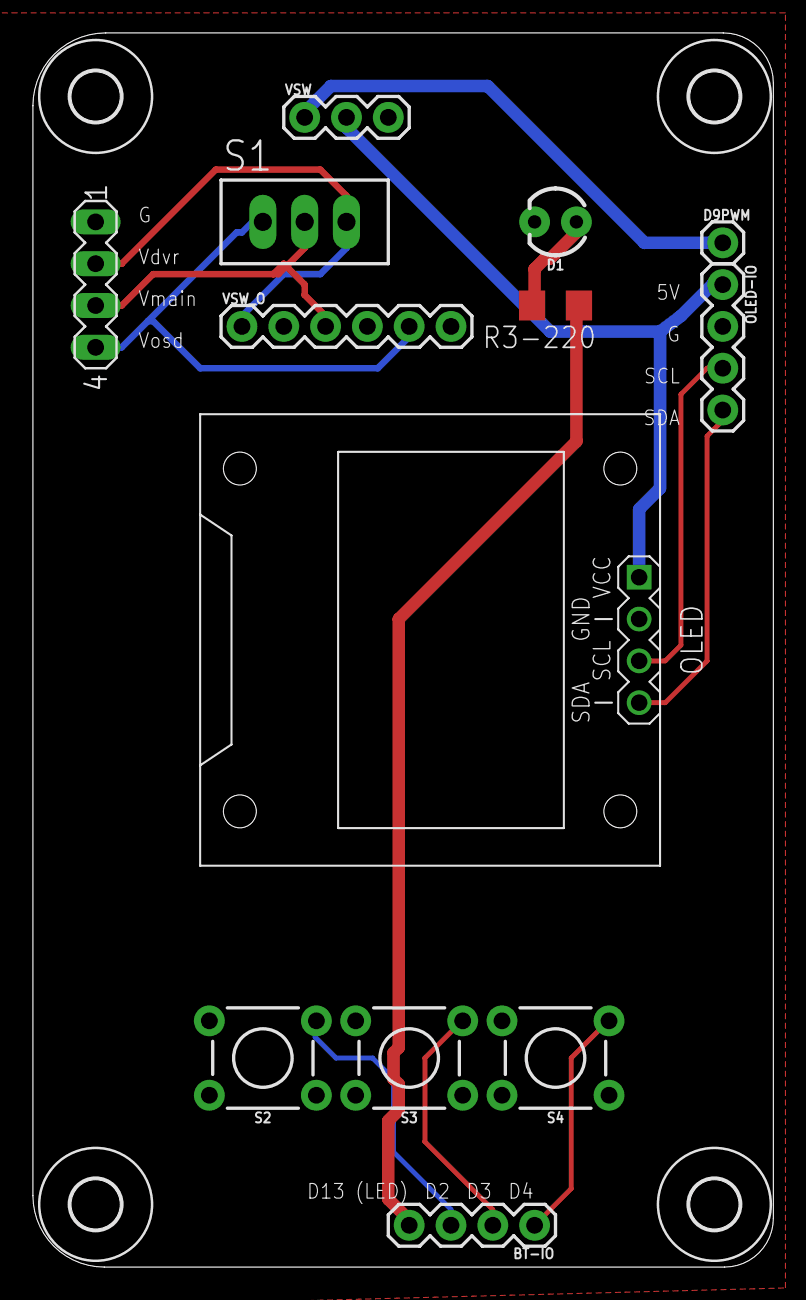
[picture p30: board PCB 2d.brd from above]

Board: 2 copper layers, 45.0 x 75.0 mm, 17 parts (0 on the bottom side), 13 nets.

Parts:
BT-IO: 1X04
D1: LED_3MM
D9PWM: 1X01
IO3: MA04-1
OLED: DISPLAY-OLED-128X64-I2C
OLED-IO: 1X04
R3-220: 220; R1206
S1: TL32PO; TL3XPO
S2, S3, S4: MOMENTARY-SWITCH-SPST-PTH-6.0MM; TACTILE_SWITCH_PTH_6.0MM
U$2, U$3, U$4, U$5: 3,0
VSW: 1X03
VSW_O: 1X06

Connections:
GND: D1.K, IO3.1, OLED.2, OLED-IO.2, S2.1, S3.1, S4.1, VSW.3, VSW_O.2, VSW_O.4, VSW_O.6
unnamed: D1.A, R3-220.2
unnamed: BT-IO.1, S4.3
unnamed: IO3.3, S1.2, VSW_O.3
unnamed: OLED.1, OLED-IO.1, VSW.2
unnamed: BT-IO.4, R3-220.1
unnamed: OLED.4, OLED-IO.4
unnamed: OLED.3, OLED-IO.3
unnamed: D9PWM.1, VSW.1
unnamed: IO3.2, S1.3, VSW_O.1
unnamed: BT-IO.2, S3.3
unnamed: BT-IO.3, S2.3
VIDOUT: IO3.4, S1.1, VSW_O.5

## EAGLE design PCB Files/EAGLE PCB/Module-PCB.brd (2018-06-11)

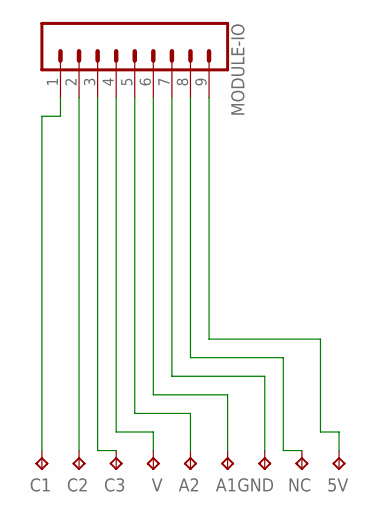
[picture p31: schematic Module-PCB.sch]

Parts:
5V: TPTP20SQ; TP20SQ
A1, A2: TPTP20SQ; TP20SQ
C1, C2, C3: TPTP20SQ; TP20SQ
GND: TPTP20SQ; TP20SQ
MODULE-IO: CONN_09; 1X09
NC: TPTP20SQ; TP20SQ
V: TPTP20SQ; TP20SQ

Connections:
3: C3.TP, MODULE-IO.3
GND: GND.TP, MODULE-IO.7
unnamed: C1.TP, MODULE-IO.1
unnamed: C2.TP, MODULE-IO.2
unnamed: MODULE-IO.4, V.TP
unnamed: A2.TP, MODULE-IO.5
unnamed: A1.TP, MODULE-IO.6
unnamed: MODULE-IO.8, NC.TP
unnamed: 5V.TP, MODULE-IO.9

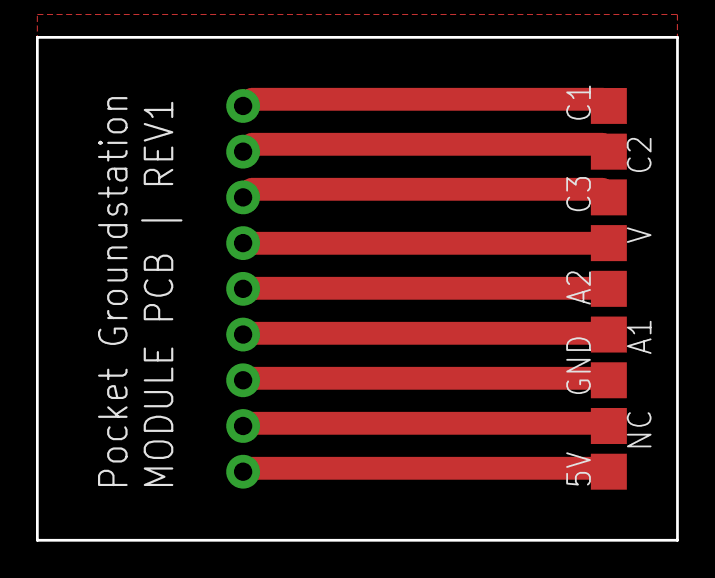
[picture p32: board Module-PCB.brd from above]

Board: 2 copper layers, 35.6 x 27.9 mm, 10 parts (1 on the bottom side), 9 nets.

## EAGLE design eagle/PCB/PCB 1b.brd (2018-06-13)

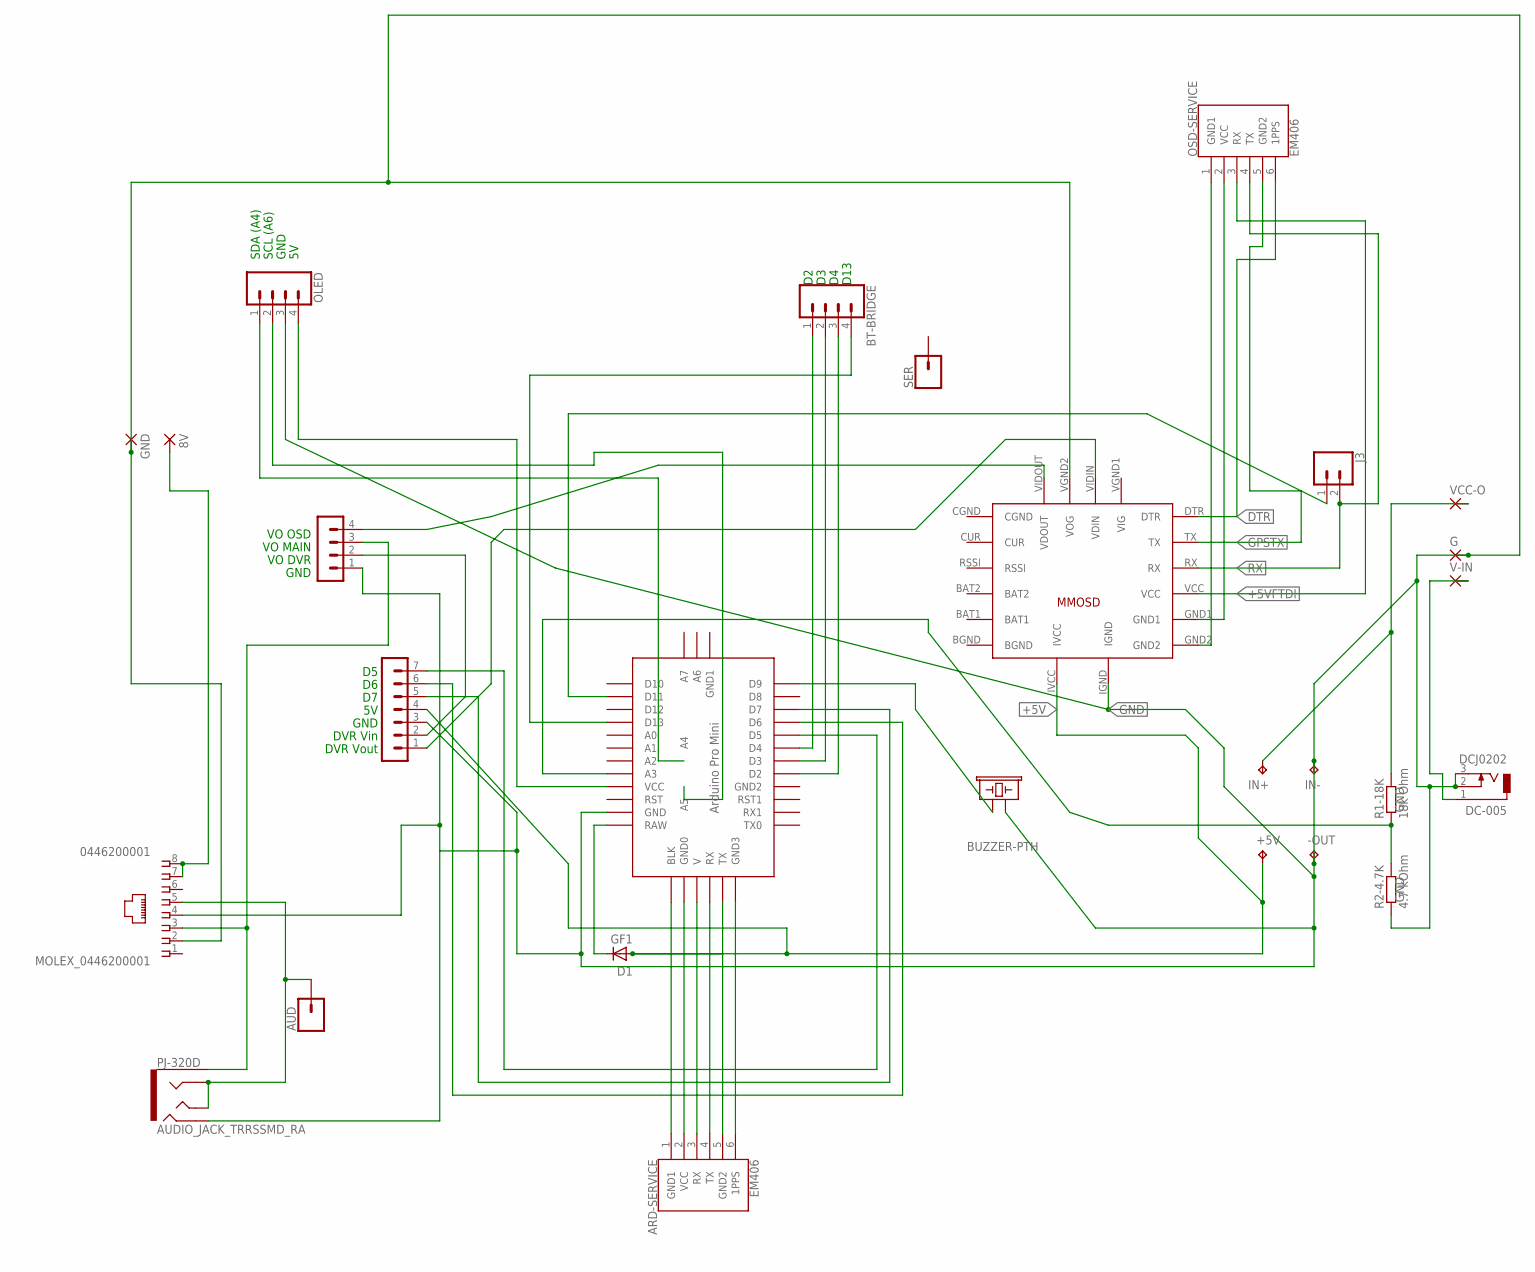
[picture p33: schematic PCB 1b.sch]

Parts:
8V: 2,54/1,1
+5V: TPTP20SQ; TP20SQ
-OUT: TPTP20SQ; TP20SQ
ARD-SERVICE: EM406; 1X06-1MM
AUD: CONN_01; 1X01
BT-BRIDGE: CONN_04; 1X04
BUZZ: BUZZER-PTH; BUZZER-12MM
D1: GF1; SMA-DO214AC
DC-005: DCJ0202
DVR/MODULE-IO: MA07-1
G: 2,54/1,1
GND: 2,54/1,1
IN+: TPTP20SQ; TP20SQ
IN-: TPTP20SQ; TP20SQ
J3: CONN_02; 1X02
MINIMOSD: MICROMINIMOSDPWR; MMOSDNVDVID
MOLEX_0446200001: 0446200001
OLED: CONN_04; 1X04
OSD-SERVICE: EM406; 1X06-1MM
PJ-320D: AUDIO_JACK_TRRSSMD_RA; AUDIO_JACK_3.5MM_TRRS_SMD_RA
R1-18K: 18k Ohm; M1206
R2-4.7K: 4.7 kOhm; M1206
SER: CONN_01; 1X01
U$1: ABK-PRO-MINI
V-IN: 2,54/1,1
V-IO: MA04-1
VCC-O: 2,54/1,1

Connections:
8V: 8V.1, MOLEX_0446200001.7, MOLEX_0446200001.8
+: DC-005.1, V-IN.1
+5V: +5V.TP, D1.A, DVR/MODULE-IO.4, MINIMOSD.IVCC
+5VFTDI: MINIMOSD.VCC, OSD-SERVICE.3 (RX)
AUDIO: AUD.1, MOLEX_0446200001.5, PJ-320D.RING1, PJ-320D.TIP
BAT1: MINIMOSD.BAT1
BAT2: MINIMOSD.BAT2
BGND: MINIMOSD.BGND
CGND: MINIMOSD.CGND
D5: DVR/MODULE-IO.7, U$1.D5
D6: DVR/MODULE-IO.6, U$1.D6
D7: DVR/MODULE-IO.5, U$1.D7
D10RX: J3.1, U$1.D11
DTR: MINIMOSD.DTR, OSD-SERVICE.6 (1PPS)
DVRVIDEO-IN: DVR/MODULE-IO.2, V-IO.2
GND: -OUT.TP, BUZZ.- (2), DC-005.2, DC-005.3, DVR/MODULE-IO.3, G.1, GND.1, IN-.TP, MINIMOSD.IGND, MINIMOSD.VGND2 (VOG), MOLEX_0446200001.2, MOLEX_0446200001.4, OLED.3, PJ-320D.RING2, R2-4.7K.1, U$1.GND, V-IO.1
GPSTX: MINIMOSD.TX, OSD-SERVICE.5 (GND2)
HP5: BT-BRIDGE.3, U$1.D2
HP6: BT-BRIDGE.1, U$1.D4
unnamed: BT-BRIDGE.2, U$1.D3
unnamed: OLED.4, U$1.VCC
unnamed: MINIMOSD.GND1, OSD-SERVICE.2 (VCC)
unnamed: D1.K (C), U$1.RAW
unnamed: MINIMOSD.GND2, OSD-SERVICE.1 (GND1)
unnamed: BT-BRIDGE.4, U$1.D13
unnamed: BUZZ.+ (1), U$1.D9
unnamed: R1-18K.1, R2-4.7K.2, U$1.A0 (A3)
unnamed: ARD-SERVICE.1 (GND1), U$1.BLK
unnamed: ARD-SERVICE.2 (VCC), U$1.G (GND0)
unnamed: ARD-SERVICE.3 (RX), U$1.5V (V)
unnamed: ARD-SERVICE.5 (GND2), U$1.TX01 (TX)
unnamed: ARD-SERVICE.6 (1PPS), U$1.DTR (GND3)
OSDSIGNAL: MINIMOSD.VIDOUT (VDOUT), V-IO.4
RAWVIDEO_MODULE: DVR/MODULE-IO.1, MINIMOSD.VIDIN (VDIN)
RX: J3.2, MINIMOSD.RX, OSD-SERVICE.4 (TX)
SCL: OLED.2, U$1.A5
SDA: OLED.1, U$1.A4
V: ARD-SERVICE.4 (TX), U$1.RX01 (RX)
VCC: IN+.TP, R1-18K.2, VCC-O.1
VMAIN: MOLEX_0446200001.3, PJ-320D.EARTH, V-IO.3

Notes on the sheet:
VO OSD
VO MAIN
VO DVR
GND
DVR Vin
DVR Vout
SDA (A4)
SCL (A6)
D13



Board: 2 copper layers, 45.0 x 75.0 mm, 27 parts (4 on the bottom side), 36 nets.

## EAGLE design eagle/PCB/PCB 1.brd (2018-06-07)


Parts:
3.5MM: 1503_10
8V-O: 2,54/1,1
+5V: SMD2; SMD1,27-2,54
+IN: SMD2; SMD1,27-2,54
-IN: SMD2; SMD1,27-2,54
-OUT: SMD2; SMD1,27-2,54
ADRUINO-NANO: NANO
BUZZ: F/CM12P
DC-JACK: DCJ0202
GND: 2,54/1,1
GND-IN: 2,54/1,1
IO1, IO2: MA07-1
IO3: MA04-1
MINIMOSD: MICROMINIMOSDPWR; MMOSDNVDVID
R1, R2: R0207/10; 0207/10
RJ45: GLX-S-88M
V-IN: 2,54/1,1
VCC-O: 2,54/1,1

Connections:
+5V: +5V.1, ADRUINO-NANO.RAW, IO1.4, MINIMOSD.IVCC
+5VFTDI: MINIMOSD.VCC
BAT1: MINIMOSD.BAT1
BAT2: MINIMOSD.BAT2
BGND: MINIMOSD.BGND
CGND: MINIMOSD.CGND
DTR: MINIMOSD.DTR
GND: MINIMOSD.GND1, MINIMOSD.GND2
GPSRX: ADRUINO-NANO.D11, MINIMOSD.RX
GPSTX: MINIMOSD.TX
HP1: ADRUINO-NANO.A4, IO2.1
HP2: ADRUINO-NANO.A5, IO2.2
HP3: 3.5MM.1, -OUT.1, ADRUINO-NANO.GND, BUZZ.- (2), IO1.3, IO2.3, IO3.1, MINIMOSD.IGND, RJ45.4
HP5: ADRUINO-NANO.D2, IO2.5
HP6: ADRUINO-NANO.D3, IO2.6
HP7: ADRUINO-NANO.D4, IO2.7
unnamed: ADRUINO-NANO.5V (5.5V), IO2.4
unnamed: ADRUINO-NANO.A0, R1.1, R2.2
unnamed: ADRUINO-NANO.D5, IO1.7
unnamed: DC-JACK.2, DC-JACK.3, V-IN.1
unnamed: 8V-O.1, RJ45.7, RJ45.8
unnamed: GND.1, RJ45.2
unnamed: ADRUINO-NANO.D6, IO1.6
unnamed: ADRUINO-NANO.D7, IO1.5
unnamed: ADRUINO-NANO.D9, BUZZ.+ (1)
unnamed: -IN.1, DC-JACK.1, GND-IN.1, R2.1
unnamed: IO1.2, IO3.2
unnamed: 3.5MM.2, IO3.3, RJ45.3
unnamed: +IN.1, R1.2, VCC-O.1
VIDIN: IO1.1, MINIMOSD.VIDIN (VDIN)
VIDOUT: IO3.4, MINIMOSD.VIDOUT (VDOUT)

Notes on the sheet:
VO OSD
VO MAIN
VO DVR
GND
DVR Vin
DVR Vout
SDA (A4)
SCL (A6)
6:NC
5:AUD

Board: 2 copper layers, 20 parts (0 on the bottom side), 24 nets, no tracks yet.

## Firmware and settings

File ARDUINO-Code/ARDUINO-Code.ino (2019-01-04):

/*
Created by Albert Kravcov
 */

#include "definesGS.h"
#include "U8glib.h"
#include <EEPROM.h>
#include <SoftwareSerial.h>
#include <Servo.h>
#include "bitmaps.h"
#include "crc16.h"

// change this depending on display type
// U8GLIB_SSD1306_128X64 u8g(U8G_I2C_OPT_DEV_0 | U8G_I2C_OPT_FAST);  // Dev 0, Fast I2C / TWI
U8GLIB_SH1106_128X64 u8g(U8G_I2C_OPT_DEV_0 | U8G_I2C_OPT_FAST);  // Dev 0, Fast I2C / TWI

typedef struct packed 
{
  const uint8_t preamble = '$';
  uint8_t paylen;
  uint8_t checksum;
  uint8_t battery_health;
  uint8_t layoutEEP;
  uint8_t DVRstatus;
  uint8_t RSSIavail;
  uint32_t RSSI;
  uint32_t VoltageByte;
} osdData_s;

#define OSD_DATA_PAYLOAD_LEN (sizeof(osdData_s)-2)
const uint8_t OSD_DATA_LENGTH_TOTAL = sizeof(osdData_s);
osdData_s osdData;

typedef __attribute__((__packed__)) struct trueDdata_t
{
  const uint8_t preamble1 = 0xFD;
  const uint8_t preamble2 = 0x07;
  uint8_t band;
  uint8_t channel;
  uint8_t rssi_max;
  uint8_t rssi1;
  uint8_t rssi2;
  const uint8_t  packet_size = 15;
}trueDdata_s;

typedef __attribute__((__packed__)) struct trueDdata_rx_t
{
  const uint8_t preamble1 = 0xFD;
  const uint8_t preamble2 = 0x07;
  uint8_t unknown1;
  uint8_t unknown2;
  uint8_t unknown3;
  uint8_t unknown4;
  uint8_t unknown5;
  uint8_t band_channel;
  uint8_t unknown6;
  uint8_t rssi_max;
  uint8_t rssi1;
  uint8_t rssi2;
  uint8_t unknown7;
  uint8_t crc_h;
  uint8_t crc_l;
}trueDdata_rx_s;

trueDdata_s trueDdata;

enum enum_trueD_packet_states {
  STATE_START = 0x00,
  STATE_GOT_PREAMBLE_1,
  STATE_GOT_PREAMBLE_2
};
uint8_t trueD_packet_state = STATE_START;


SoftwareSerial OSDsoft(10, 11); // RX, TX

float voltage;
int32_t lipo;
float alarmvalue = 3.40;
int32_t alarmvalueEEP;
int32_t DVRstatus = 0;
int32_t layoutEEP = 0;
int32_t rssiEEP = 0;
int dvrEEP = 0;
int32_t osddata;
int32_t RSSIavail;
int32_t RSSI = 69;
int32_t VoltageByte;
int refreshi = 0;
int volti = 0; // Counter for Voltage measure
int menusel = 0;
int pressedbut = 0;
float cellvoltage;
int osdON;
int32_t battery_health = 0;
int dvr_sensor;
unsigned long timeDVRblink = 0;
unsigned long LEDMillis = 0;
unsigned long RSSIMillis = 0;
unsigned long DVRdelay = 0;
int LEDState = LOW;
Servo pwmSwitch;  // create servo object to control a servo


void pause()
{
    while (1);
}

void OSDsend()
{
    osdData.paylen = OSD_DATA_PAYLOAD_LEN;
    osdData.battery_health = battery_health;
    osdData.layoutEEP = layoutEEP;
    osdData.DVRstatus = DVRstatus;
    osdData.RSSIavail = RSSIavail;
    osdData.RSSI = trueDdata.rssi_max;
    osdData.VoltageByte = VoltageByte;
  
    uint8_t checksum = 0;
    for (int i = 3; i< OSD_DATA_LENGTH_TOTAL; i++) {
      checksum ^= ((uint8_t*)&osdData)[i];
    }
    osdData.checksum = checksum;

    OSDsoft.write((uint8_t*)&osdData, sizeof(osdData));
    
    RSSIavail = rssiEEP;
}


void setup()
{
    trueDdata.band = 0;
    trueDdata.channel = 0;
    trueDdata.rssi_max = 0;
    trueDdata.rssi1 = 0;
    trueDdata.rssi2 = 0;

    pinMode(BUTTON1_PIN, INPUT_PULLUP);
    pinMode(BUTTON2_PIN, INPUT_PULLUP);
    pinMode(BUTTON3_PIN, INPUT_PULLUP);

    pinMode(DVR1_PIN, OUTPUT); //DVR Key1
    pinMode(DVR2_PIN, OUTPUT); //DVR Key2
    pinMode(DVR3_PIN, OUTPUT); //DVR Key3
    pinMode(DVR_SENS, INPUT); //DVR LED Sensor

    pinMode(STATUS_LED, OUTPUT); //StatusLED
    
    digitalWrite(DVR1_PIN, HIGH);
    digitalWrite(DVR2_PIN, HIGH);
    digitalWrite(DVR3_PIN, HIGH);

    pwmSwitch.attach(9);  // attaches the servo on pin 9 to the servo object


    alarmvalueEEP = EEPROM.read(alarmADDR);
    layoutEEP = EEPROM.read(layoutADDR);
    dvrEEP = EEPROM.read(dvrADDR);
    rssiEEP = EEPROM.read(rssiADDR);

    
    if (alarmvalueEEP != 0)  
    {
        alarmvalue = (alarmvalueEEP / 10.0);
    }
    if (alarmvalueEEP > 250)
    {
        alarmvalue = 3.40;
    }
    else { }

 if (layoutEEP > 2)  
    {
        layoutEEP = 1;
    }
    else
    { }

     if (dvrEEP > 1)  
    {
        dvrEEP = 0;
    }
    else
    { }

     if (rssiEEP > 1)  
    {
        rssiEEP = 0;
    }
    else
    { }
    
    Serial.begin(9600);
    OSDsoft.begin(9600);


    if ( u8g.getMode() == U8G_MODE_R3G3B2 ) 
    {
        u8g.setColorIndex(255);     // white
    }
    else if ( u8g.getMode() == U8G_MODE_GRAY2BIT ) 
    {
        u8g.setColorIndex(3);         // max intensity
    }
    else if ( u8g.getMode() == U8G_MODE_BW ) 
    {
        u8g.setColorIndex(1);         // pixel on
    }
    else if ( u8g.getMode() == U8G_MODE_HICOLOR ) 
    {
        u8g.setHiColorByRGB(255, 255, 255);
    }


    clearOLED();
    showlogo();
    delay(100);

    voltagetest();

    
    if (voltage > (Voltagedetect * 5.0))
    {
        lipo = 4;
        //beep_x(lipo);
    }
    else if (voltage > (Voltagedetect * 4.0))
    {
        lipo = 4;
        //beep_x(lipo);
    }
    else if (voltage > (Voltagedetect * 3.0))
    {
        lipo = 3;
       // beep_x(lipo);
    }
    else if (voltage > (Voltagedetect * 2.0))
    {
        lipo = 2;
        //beep_x(lipo);
    }
    else
    {
        //pause();
        lipo = 1;
       // beep_x(lipo);
    }
}


void clearOLED() 
{
    u8g.firstPage();
    do 
    {
    } 
    while( u8g.nextPage() );
}


void showlogo()
{
    u8g.firstPage();
    do 
    {
      // splashscreen goes here
      u8g.drawBitmapP(15, 10, 12, 46, splash_bitmap);
    }
    while (u8g.nextPage());
    delay(1500);
    clearOLED();
}


void voltagetest()
{

    int sensorValue = analogRead(A0); // read the input on analog pin 0:
    voltage = sensorValue * (5.52 / 1023.0) * ((R1 + R2) / R2); // Convert the analog reading (which goes from 0 - 1023) to a voltage, considering the voltage divider:
    // Serial.println(voltage);   // print out the value you read:
    voltage = round(voltage * 10) / 10.0; //round the result
    VoltageByte = voltage*10;

    cellvoltage = voltage / lipo;


    float cellfull = (max_cellvoltage) - (alarmvalue); //determine 100% of travel scale
    float cellstate = (max_cellvoltage) - (cellvoltage); //determine the actual cell delta value
    float battery_state = 100 - (((cellstate)*100) / (cellfull)); //determine cell charge left in percent

    if (battery_state >= 75 && battery_state < 100) 
    {
        battery_health = 4;
    }
    else if (battery_state >= 50 && battery_state < 75) 
    {
        battery_health = 3;
    }
    else if (battery_state >= 25 && battery_state < 50) 
    {
        battery_health = 2;
    }
    else if (battery_state >= 5 && battery_state < 25) 
    {
        battery_health = 1;
    }
    else if (battery_state >= 0) 
    {
        battery_health = 0;
    }
    else {
        battery_health = 0;
    }

    

  
}


byte buttoncheck()
{
    int i_butt = 0;
    byte buttonz = 0;
    if (digitalRead(BUTTON1_PIN) != 1)
    {
        while(digitalRead(BUTTON1_PIN) != 1)
        {
            delay(2);
            i_butt++;
        }
        buttonz = 1;
        tone(beeppin, note, 10); // 10ms beep (C4 Tone)
        
        if (i_butt > (longpresstime / 2))
        {
          buttonz += 3;
          tone(beeppin, note, 100); // 100ms beep (C4 Tone)
        }
    }

    else if (digitalRead(BUTTON2_PIN) != 1)
    {
        while(digitalRead(BUTTON2_PIN) != 1)
        {
            delay(2);
            i_butt++;
        }
        buttonz = 2;
        tone(beeppin, note, 10); // 10ms beep (C4 Tone)
        
        if (i_butt > (longpresstime / 2))
        {
          buttonz += 3;
          tone(beeppin, note, 100); // 100ms beep (C4 Tone)
        }

    }
    else if (digitalRead(BUTTON3_PIN) != 1)
    {
        while(digitalRead(BUTTON3_PIN) != 1)
        {
            delay(2);
            i_butt++;
        }
        buttonz = 3;
        tone(beeppin, note, 10); // 10ms beep (C4 Tone)
        
        if (i_butt > (longpresstime / 2))
        {
          buttonz += 3;
          tone(beeppin, note, 100); // 100ms beep (C4 Tone)
        }
    }

    pressedbut = buttonz;
    return buttonz;
}


void ledcheck() 
{

 if (battery_health > 0) 
 {
   dvr_sensor = analogRead(DVR_SENS);
    if  (dvr_sensor < 300) 
  {
  digitalWrite(STATUS_LED, HIGH); 
  }
  else 
  {
    digitalWrite(STATUS_LED, LOW); 
    }
}
  else if (battery_health == 0)
  {
   unsigned long currentLEDMillis = millis();
    if ((currentLEDMillis - LEDMillis >= 300))
   {
      LEDMillis = currentLEDMillis;
 
       if (LEDState == LOW) {
          LEDState = HIGH;
          tone(beeppin, note, 300); // 300ms beep (C4 Tone)
        } 
        else {
          LEDState = LOW;
        } 
    digitalWrite(STATUS_LED, LEDState); 
  }
  
}
}


void DVRautostart() // experimental
{
  
 
 if (trueDdata.rssi_max > 70 && DVRstatus == 0)
  { 
    unsigned long currentDVRdelay = millis();
    if (currentDVRdelay - DVRdelay >= 500) {
   // code for starting the DVR
    digitalWrite(DVR1_PIN, LOW);
    delay(480);
    digitalWrite(DVR1_PIN, HIGH);
    delay(5);
    DVRdelay = currentDVRdelay;
    }
    else
    {
      DVRdelay = currentDVRdelay;
    }
  }
    if (trueDdata.rssi_max < 20 && DVRstatus == 1 )
  {
    unsigned long currentDVRdelay = millis();
    if (DVRdelay > 500) {
   // code for stopping the DVR
    digitalWrite(DVR1_PIN, LOW);
    delay(480);
    digitalWrite(DVR1_PIN, HIGH);
    delay(5);
    DVRdelay = currentDVRdelay;
  }
  else {
    DVRdelay = currentDVRdelay;
    }
  }
  else {}
}

void loop()
{

    if (trueD_packet_state == STATE_START && OSDsoft.available()) {
      uint8_t rx = OSDsoft.read();
      trueD_packet_state = (rx == trueDdata.preamble1) ? STATE_GOT_PREAMBLE_1 : trueD_packet_state;

    }
    else if (trueD_packet_state == STATE_GOT_PREAMBLE_1 && OSDsoft.available()) {
      uint8_t rx = OSDsoft.read();
      trueD_packet_state = (rx == trueDdata.preamble2) ? STATE_GOT_PREAMBLE_2 : STATE_START;

    }
    else if (trueD_packet_state == STATE_GOT_PREAMBLE_2 && OSDsoft.available() >= trueDdata.packet_size - 2) {
      trueDdata_rx_s trueDdata_rx;
      OSDsoft.readBytes(&trueDdata_rx.unknown1, trueDdata.packet_size - 2);
      uint16_t crc_rx = ((uint16_t)trueDdata_rx.crc_h << 8) | trueDdata_rx.crc_l;
      uint16_t crc_calc = crc16_ccitt(&trueDdata_rx.preamble1, trueDdata.packet_size - 2);
      if (crc_rx == crc_calc) { //got complete data frame + crc match
        trueDdata.band = (trueDdata_rx.band_channel >> 3);
        trueDdata.channel = trueDdata_rx.band_channel & 0x07;
        trueDdata.rssi_max = trueDdata_rx.rssi_max / 2;
        trueDdata.rssi1 = trueDdata_rx.rssi1 / 2;
        trueDdata.rssi2 = trueDdata_rx.rssi2 / 2;
      }
    }

    pwmSwitch.write(150);

    if (layoutEEP == 1)
    {
        osdON = true;
    }
    else if (layoutEEP == 2)
    {
        osdON = true;
    }
    else if (layoutEEP == 0)
    {
        osdON = false;
    }
    else {
        osdON = false;
    }

    
    // Some debug output:
    
    // Serial.print("health: ");
    // Serial.print(battery_health);

    // Serial.print(" state: ");
    // Serial.print(battery_state);

    // Serial.print(" alarmvalueEEP: ");
    // Serial.print(alarmvalueEEP);

    // Serial.print(" layoutEEP: ");
    // Serial.print(layoutEEP);

    // Serial.print(" DVRstatus: ");
    // Serial.print(DVRstatus);

    // Serial.print(" VoltageByte: ");
    // Serial.print(VoltageByte);

    // Serial.print(" dvrEPP: ");
    // Serial.print(dvrEEP);

    //Serial.print(" RSSI max: ");
    //Serial.print(trueDdata.rssi_max);

    //Serial.print(" RSSI 1: ");
    //Serial.print(trueDdata.rssi1);

    //Serial.print(" RSSI 2: ");
    //Serial.print(trueDdata.rssi2);

    Serial.println();

    ledcheck();

    refreshi++;
    if(refreshi > 1)
    {
        volti++;
        if(volti > 5)
        {
            voltagetest();
            volti = 0;
        }
        u8g.firstPage();

        OSDsend();

        do {
            // graphic commands to redraw the complete screen should be placed here
            
            u8g.setFont(u8g_font_5x7r);
            u8g.setPrintPos(16, 9);
            u8g.print(lipo);
            u8g.setFont(u8g_font_5x7r);
            u8g.setPrintPos(22, 9);
            u8g.print("S");
            



           if(rssiEEP == 0) 
                {
                    u8g.setFont(u8g_font_5x7r);
                    u8g.setPrintPos(32, 9);
                    u8g.print("BATTERY");
                    u8g.setFont(u8g_font_profont22r);
                    u8g.setPrintPos(0, 36);
                    u8g.print(voltage, 1);
            
                    if (voltage > 10.0) {
                      u8g.setPrintPos(52, 36);
                      u8g.print("v");
                    }
                    else if (voltage < 10.0)
                    {
                      u8g.setPrintPos(40, 36);
                      u8g.print("v");
                    }
                    else {}

                }
            
             
             if(rssiEEP == 1) 
               { 
                int barpercent = trueDdata.rssi_max * 0.6;
                
                u8g.setFont(u8g_font_5x7r);
                u8g.setPrintPos(29, 9);
                u8g.print("BATTERY");
            
                u8g.setPrintPos(67, 9);
                u8g.print(voltage, 1);
                u8g.print("v");

                    
                u8g.setFont(u8g_font_profont22r);
                u8g.setPrintPos(0, 29);
                

                if (trueDdata.band == 0) {
                  u8g.print("A");
                  }
                else if (trueDdata.band == 1) {
                  u8g.print("B");
                  }
                else if (trueDdata.band == 2) {
                  u8g.print("E");
                  }
                else if (trueDdata.band == 3) {
                  u8g.print("F");
                  }
                else if (trueDdata.band == 4) {
                  u8g.print("R");
                  }
                else if (trueDdata.band == 5) {
                  u8g.print("L");
                  }
                
                
                u8g.print(trueDdata.channel +1);
                u8g.setPrintPos(25, 28);
                u8g.setFont(u8g_font_5x7r);
                u8g.print(" > ");
                u8g.print(trueDdata.rssi_max);
                u8g.print("%");
                
                u8g.drawBox(3,35,barpercent,3); // 
                u8g.drawFrame(1,33,64,7);


                
                
                if (trueDdata.rssi1 > trueDdata.rssi2) 
                {
                u8g.drawBox(70,18,11,22);
                u8g.drawFrame(80,18,12,22);
                u8g.setFont(u8g_font_5x7r);
                u8g.setPrintPos(74,32);
                u8g.setColorIndex(0);
                u8g.print("A");
                u8g.setColorIndex(1);  
                u8g.setPrintPos(84,32);
                u8g.print("B");
                }

                 else
                {
                u8g.drawFrame(70,18,12,22);
                u8g.drawBox(80,18,11,22);
                u8g.setFont(u8g_font_5x7r);
                u8g.setPrintPos(74,32);
                u8g.print("A");
                u8g.setPrintPos(84,32);
                u8g.setColorIndex(0);
                u8g.print("B");
                u8g.setColorIndex(1);                 
                }
                
                
               }
            
            


            u8g.drawFrame(1, 48 - 2, 124, 18);
            u8g.setFont(u8g_font_5x7r);
            u8g.setPrintPos(12, 58);
            u8g.print("PRESS CENTER FOR MENU");


            dvr_sensor = analogRead(DVR_SENS);
            if (dvr_sensor < 300) //if DVR LED is blinking
            {   
                DVRstatus = 1;  
                timeDVRblink = millis();
            } 
            
            else
            {
                if(millis() - timeDVRblink > 1500)
                {
                  DVRstatus = 0;
                }
            }
             
           
            if (DVRstatus == 1) 
            {
             u8g.drawBitmapP(96, 2, 1, 8, DVRstatus8_bitmap);
             u8g.setPrintPos(108, 9);
             u8g.print("REC");
            }


            if(osdON == true)
            {
                u8g.setPrintPos(111, 9);
                u8g.print("OSD");
            }

            u8g.drawFrame(96, 18 - 1, 29, 23);
            u8g.drawBox(96, 18, 29, 6);
            u8g.setPrintPos(101, 35);
            u8g.print(alarmvalue);
            u8g.setColorIndex(0);
            u8g.setPrintPos(101, 23);
            u8g.setFont(u8g_font_micro);
            u8g.print("ALARM");
            u8g.setColorIndex(1);

            if (battery_health == 4) // case if voltage is 75% +
            {
                u8g.drawBox(2, 5, 1, 2);
                u8g.drawBox(4, 5, 1, 2);
                u8g.drawBox(6, 5, 1, 2);
                u8g.drawBox(8, 5, 1, 2);
                u8g.drawFrame(0, 5 - 2, 11, 6);
                u8g.drawBox(11, 5, 1, 2);
            }
            else if (battery_health == 3) // case if voltage is 50% +
            {
                u8g.drawBox(2, 5, 1, 2);
                u8g.drawBox(4, 5, 1, 2);
                u8g.drawBox(6, 5, 1, 2);
                u8g.drawFrame(0, 5 - 2, 11, 6);
                u8g.drawBox(11, 5, 1, 2);
            }
            else if (battery_health == 2) // case if voltage is 25% +
            {
                u8g.drawBox(2, 5, 1, 2);
                u8g.drawBox(4, 5, 1, 2);
                u8g.drawFrame(0, 5 - 2, 11, 6);
                u8g.drawBox(11, 5, 1, 2);
            }
            else if (battery_health == 1) // case if voltage is 5% +
            {

                u8g.drawBox(2, 5, 1, 2);
                u8g.drawFrame(0, 5 - 2, 11, 6);
                u8g.drawBox(11, 5, 1, 2);
            }
            else
            {
                u8g.drawFrame(0, 5 - 2, 11, 6);
                u8g.drawBox(11, 5, 1, 2);
            }


            if (dvrEEP == 1) 
             {
                 DVRautostart();
             }

    

        }
        while (u8g.nextPage()
              );
        refreshi = 0;

    }

    buttoncheck();
    
    if (pressedbut == 1)
    {
        menu();
    }

    if (pressedbut == 4)
    {
      if (dvrEEP == 0) 
      {
        digitalWrite(DVR1_PIN, LOW);
        delay(480);
        digitalWrite(DVR1_PIN, HIGH);
        delay(5);
       }
       else {}
        
    }

    if (pressedbut == 3)
    {
        if (alarmvalue > 2.70)
        {
            alarmvalue -= 0.10;
            alarmvalueEEP = alarmvalue * 10.0;
            EEPROM.write(alarmADDR, alarmvalueEEP);
        }
    }

    if (pressedbut == 2)
    {
        if (alarmvalue < 3.90)
        {
            alarmvalue += 0.10;
            alarmvalueEEP = alarmvalue * 10.0;
            EEPROM.write(alarmADDR, alarmvalueEEP);
        }
    }


    delay(DELAY);

}



// Beep-Stuff


void beep_x(byte b)
{
    for (int i = 1; i <= b; i++)
    {
        tone(beeppin, note, 200);
        delay(400);
    }
}


void menu()
{
    menusel = 0;
    byte exit = 0;
    while(exit == 0)
    {
        clearOLED();
        u8g.firstPage();
        do
        {
            if(menusel == 0)
            {
                u8g.drawBitmapP(43, 8, 6, 35, DVR42_bitmap);
                u8g.setFont(u8g_font_5x7r);
                u8g.setPrintPos(45, 55);
                u8g.print("DVR MODE");

                u8g.drawDisc(115, 23, 2);
                u8g.drawCircle(115, 33, 2);
                u8g.drawCircle(115, 43, 2);

            }
            else if(menusel == 1)
            {
                u8g.drawBitmapP(43, 10, 6, 35, settings42_bitmap);
                u8g.setFont(u8g_font_5x7r);
                u8g.setPrintPos(44, 55);
                u8g.print("SETTINGS");

                u8g.drawCircle(115, 23, 2);
                u8g.drawDisc(115, 33, 2);
                u8g.drawCircle(115, 43, 2);
            }
            else if(menusel == 2)
            {
                u8g.drawBitmapP(43, 10, 6, 35, EXIT_bitmap);
                u8g.setFont(u8g_font_5x7r);
                u8g.setPrintPos(58, 55);
                u8g.print("EXIT");

                u8g.drawCircle(115, 23, 2);
                u8g.drawCircle(115, 33, 2);
                u8g.drawDisc(115, 43, 2);
            }
        }
        while (u8g.nextPage());

        pressedbut = buttoncheck();
        while(pressedbut == 0)
        {
            buttoncheck();
            ledcheck(); 
        }
        if(pressedbut == 1)
        {
            // Press selected Menu Point
            if(menusel == 2)
            {
                refreshi = 10;
                exit = 1;
            }
            if(menusel == 1)
            {
                refreshi = 10;
                exit = 1;
                submenu();
            }
            if(menusel == 0)
            {
                refreshi = 10;
                exit = 1;
                dvrmenu();
            }

        }
        else if(pressedbut == 2)
        {
            if(menusel > 0)
            {
                menusel--;
            }
        }
        else if(pressedbut == 3)
        {
            if(menusel < 2)
            {
                menusel++;
            }
        }
    }


}
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

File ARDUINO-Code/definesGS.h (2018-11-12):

#define fwversion              1.0  // Pocket Groundstation version

#define Voltagedetect          3.25 // Min. voltage for Detection
#define max_cellvoltage        4.25 // Max. cell voltage
#define R1                   18000  // Resistor 1
#define R2                    4700  // Resistor 2 (measured)

#define note                   200  // C4

#define alarmADDR                1  // EEPROM Adress
#define layoutADDR               2  // OSD Layout Adress
#define dvrADDR                  3  // DVR Settings Adress
#define rssiADDR                 4  // RSSI Settings Adress

#define BUTTON1_PIN              3  // Button 1
#define BUTTON2_PIN              4  // Button 2
#define BUTTON3_PIN              2  // Button 3
#define DVR1_PIN                 5  // DVR Button 1
#define DVR2_PIN                 6  // DVR Button 2
#define DVR3_PIN                 7  // DVR Button 3
#define DVR_SENS                A1  // DVR LED Sensor
#define STATUS_LED              13  // Status LED
#define beeppin                  8  // Beeper Pin (changed from 9)

#define DELAY                    2  // Delay per loop in ms
#define longpresstime         1000  // in ms

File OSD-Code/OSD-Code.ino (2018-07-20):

#include <SPI.h>
#include <max7456.h>

#define redLed 3
#define greenLed 4

typedef struct packed 
{
  const uint8_t preamble = '$';
  uint8_t paylen;
  uint8_t checksum;
  uint8_t battery_health;
  uint8_t layoutEEP;
  uint8_t DVRstatus;
  uint8_t RSSIavail;
  uint32_t RSSI;
  uint32_t VoltageByte;
} osdData_s;

static enum _serial_state {
  IDLE,
  HEADER_START,
  HEADER_SIZE,
} c_state = IDLE;


#define OSD_DATA_PAYLOAD_LEN (sizeof(osdData_s)-2)
const uint8_t OSD_DATA_LENGTH_TOTAL = sizeof(osdData_s);
osdData_s osdData;

float alarmvalue;
float cellvoltage;
int32_t osddata = 0;
int32_t layoutEEP = 0;
int32_t oldlayout;
int32_t newlayout;
int32_t blinkosd = 0;
int32_t DVRstatus = 0;
int32_t RSSIavail = 0;
int32_t oldRSSI;
int32_t oldDVR;
int32_t RSSI = 0;
int32_t VoltageByte = 0;
float Voltage;
int32_t battery_health = 0;
unsigned long Protocoltime = 0;
unsigned long Layouttime = 0;
unsigned long BatTime = 0;
int BatWarningstate = 0;


Max7456 osd;
byte logo1[]={0xC0,0xC1,0xC2,0xC3,0xC4,0xC5,0xC6,0xC7,0xC8,0xC9,0xCA,0xCB,0xCC };
byte logo2[]={0xD0,0xD1,0xD2,0xD3,0xD4,0xD5,0xD6,0xD7,0xD8,0xD9,0xDA,0xDB,0xDC };
byte logo3[]={0xE0,0xE1,0xE2,0xE3,0xE4,0xE5,0xE6,0xE7,0xE8,0xE9,0xEA,0xEB,0xEC };
byte logo4[]={0xF0,0xF1,0xF2,0xF3,0xF4,0xF5,0xF6,0xF7,0xF8,0xF9,0xFA,0xFB,0xFC };


void setup()
{
  SPI.begin();
  Serial.begin(9600);


  osd.init(6);
  osd.setDisplayOffsets(32,18);
  osd.setBlinkParams(_8fields, _BT_BT);
 
  osd.activateOSD();
  
  // mark max screen size to adjust offset
  // osd.printMax7456Char(0x01,0,0);
  // osd.printMax7456Char(0x01,0,15);
  // osd.printMax7456Char(0x01,29,0);
  // osd.printMax7456Char(0x01,29,15);
  
  pinMode(redLed,OUTPUT);
  pinMode(greenLed,OUTPUT);
  
  //base time = 160ms,time on = time off.

  splash();
}

void OSDreceive()
{
  uint8_t c;
  static uint8_t payloadIdx = 2;
  static osdData_s osdDataBuffer;
  
  while (Serial.available()) {

    c = Serial.read();

    if (c_state == IDLE) { // try to read preamble
      c_state = (c == '$') ? HEADER_START : IDLE;

    }
    else if (c_state == HEADER_START) { // try to read packet length
      c_state = (c == OSD_DATA_PAYLOAD_LEN) ? HEADER_SIZE : IDLE;
      osdDataBuffer.paylen = c;
      payloadIdx = 2;

    }else if (c_state == HEADER_SIZE) { // try to read payload

      if (payloadIdx >= OSD_DATA_LENGTH_TOTAL) { // got all data bytes
                             // data complete, verify checksum        
        uint8_t checksum = 0;
        for (int i = 3; i < OSD_DATA_LENGTH_TOTAL ; i++){
          checksum ^= ((uint8_t*)&osdDataBuffer)[i];
        }

        if (checksum == osdDataBuffer.checksum) {
          memcpy( &osdData, &osdDataBuffer, OSD_DATA_LENGTH_TOTAL);
          battery_health = osdData.battery_health;
          layoutEEP = osdData.layoutEEP;
          DVRstatus = osdData.DVRstatus;
          RSSIavail = osdData.RSSIavail; 
          RSSI = osdData.RSSI;
          VoltageByte = osdData.VoltageByte;
        }
        c_state = IDLE; //done, start over

      } else {
        ((char*)&osdDataBuffer)[payloadIdx++] = c;
      }
    }
  }
}

void splash()
{
  osd.printMax7456Chars(logo1,12,9,5);
  osd.printMax7456Chars(logo2,12,9,6);
  osd.printMax7456Chars(logo3,12,9,7);
  osd.printMax7456Chars(logo4,12,9,8);
  delay(2000);
  osd.clearScreen();
  }


void checkChanges()
  {
    
    unsigned long refreshtime = millis();
  if ((RSSIavail != oldRSSI) && (refreshtime >= 20))
    {
    refreshtime = 0;
    oldRSSI = RSSIavail;
    osd.clearScreen();
    }
    
    else if ((layoutEEP != oldlayout) && (refreshtime >= 20))
    {
    refreshtime = 0;
    newlayout = layoutEEP;
    osd.clearScreen();
    
    }
    
      if (DVRstatus != oldDVR) 
    {
    oldDVR = DVRstatus;
    osd.clearScreen();
    
    }   
    else 
    { 
     }
  }

void baticon()
{
 
 }
  
void loop()
{
    

  unsigned long currentLayouttime = millis();
    if ((currentLayouttime - Layouttime >= 200))
    {
      Layouttime = currentLayouttime;
    
  if (Serial.available() > 0)
  {    
    OSDreceive();
    checkChanges();
  }
 double Osvoltage = (VoltageByte / 10.0);
 double OslayoutEEP = layoutEEP;
 double OsRSSI = RSSI;
 double OsDVRstatus = DVRstatus;
 double Osblinkosd = blinkosd;
 double OsRSSIavail = RSSIavail;
 double OsHealth = battery_health;
 
  

   
      
   if (newlayout == 1) // Layout1
  { 
    oldlayout = 1;
    
  if (RSSIavail == 1) 
    {
    // RSSI printout
    osd.printMax7456Char(0x94,24,6);
    osd.print(OsRSSI,25,6, 2, 0);
    osd.printMax7456Char(0x7F,27,6); //black 
    osd.printMax7456Char(0x7F,28,6); //black 
    osd.printMax7456Char(0x7F,29,6); //black 
    oldRSSI = RSSIavail;
    }
    else {   }

    
    // voltage printout
    osd.printMax7456Char(0x7F,29,7); //black 
    osd.printMax7456Char(0x7F,24,7); //black
    
    if (battery_health == 4) 
    {
      osd.printMax7456Char(0x8F,24,7);
    }
    else if (battery_health == 3) 
    {
      osd.printMax7456Char(0x90,24,7);
    }
     else if (battery_health == 2) 
    {
      osd.printMax7456Char(0x91,24,7);
    }
     else if (battery_health == 1) 
    {
      osd.printMax7456Char(0x92,24,7);
    }
    
     else if (battery_health == 0) 
    {
    
          unsigned long CurrentBat = millis();
      if ((CurrentBat - BatTime >= 300))
      {
        BatTime = CurrentBat;
        if (BatWarningstate == 0)  
        {
        BatWarningstate = 1;
        }
        else 
        {
        BatWarningstate = 0;
        }
      

        if (BatWarningstate == 1) 
        {
        osd.printMax7456Char(0x93,24,7);
        }
        else 
        {
        
        }
           
      }
      
     } 
      
      
      else
    {
      
    }    

      
    if (Osvoltage > 10) {
    osd.print(Osvoltage, 25, 7, 2, 1); 
    
    }
    else if (Osvoltage < 10) {
    osd.print(Osvoltage, 25, 7, 1, 1);
    osd.printMax7456Char(0x7F,28,7); //black 
    }
    
    
  // DVR printout
  if (DVRstatus == 1) 
  {
    osd.printMax7456Char(0x99,24,8);
    osd.print("REC",25,8);
    osd.printMax7456Char(0x7F,28,8); //black 
    osd.printMax7456Char(0x7F,29,8); //black 
  }
  else {}


  
  

 // osd.print("VOLTAGE",1,3);
 // osd.print(Osvoltage, 9, 3, 2, 1); // test for voltage
  
 // osd.print("OSD LAY",1,4);
 // osd.print(OslayoutEEP, 9, 4, 1, 0); // test for OSD layout

 // osd.print("RSSI",1,5);
 // osd.print(OsRSSI, 9, 5, 2, 0); // test for RSSI strenght

 // osd.print("DVR",1,6);
 //  osd.print(OsDVRstatus, 9, 6, 1, 0); // test for DVR status

 //  osd.print("BLINK",1,7);
 // osd.print(Osblinkosd, 9, 7, 1, 0); // test for alarm status

 // osd.print("RS-A",1,8);
 // osd.print(OsRSSIavail, 9, 8, 1, 0); // test if RSSI is available

 // osd.print("HEALTH",1,9);
 // osd.print(OsHealth, 9, 9, 1, 0); // test if battery-health is available
  
  
  }

  
   if (newlayout == 2) {
    
     oldlayout = 2;
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

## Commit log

2018-05-25 Some initial concept files
    [Module Insert.stl]
2018-05-25 new stl
    [Module Insert.stl, module insert v08.stl]
2018-05-25 More 3D work
    [body.stl, body_fixed.stl, module insert.stl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]
2018-05-26 third button added
2018-05-28 Voltage Divider + cleanup
    Added Voltage Divider.
    Little Cleanup and beeping works now with tone.
2018-05-28 Added Voltage Detection
    Added Voltage Detection and minor stuff
2018-05-28 Handle Buttons
2018-05-29 voltage detection cleanup
2018-05-29 rowork battery alarm
2018-05-29 3D update
    [body.stl, body_fixed.stl, module insert.stl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]
2018-06-05 adjusting "v" printout if voltage is >10v
2018-06-05 C3
    C3
    [C3.csv, C3.xlsx]
2018-06-06 PCB work
    [PCB Albert.brd, PCB Albert.sch]
2018-06-08 More PCB work
    [PCB 1b.brd, PCB 1b.sch, PCB 2.brd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]
2018-06-08 PCB Update
2018-06-11 Update PCB components
    [Module-PCB.brd, PCB 1b.brd, PCB 1b.sch]
2018-06-11 PCB updates
    [Module-PCB.brd, Module-PCB.sch, PCB 1b.brd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]
2018-06-12 added further info about serial protocol moved protocol files to separate folder
    [C3.csv, C3.xlsx, protocol.xlsx]
2018-06-13 small PCB updates
    [PCB 1b.brd, PCB 1b.sch, PCB 2.brd]
2018-06-13 minor pcb adjustments
    [PCB 1c.brd, PCB 2c.brd]
2018-06-14 Component change
    [PCB 1c.brd, PCB 1c.sch]
2018-06-14 resistor values
2018-06-14 ref voltage
2018-06-14 battery_health
    battery_health
2018-06-15 change button direction
2018-06-15 dynamic battery icon
    changes according the set min cell voltage alarm
2018-06-16 checking dvr status with DVR LED sensing
2018-06-16 dvr sensor
2018-06-18 remove some dvr menu buttons
2018-06-19 remove serial print
2018-06-19 LED change
2018-06-19 PCB change
    [PCB 1c.brd, PCB 1c.sch]
2018-06-21 Status LED
2018-06-21 change led
2018-06-21 more led conditions
2018-06-21 bot more accurate voltage scaling
2018-06-21 PWM videoswitch support
2018-06-23 New PCB versions
    • Changed buzzer pin to D9
    • D8 goes to PCB 2 now
    • PCB 2 has a new option for mounting a PWM videoswitch
    [PCB 1d.brd, PCB 1d.sch, PCB 2d.brd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]
2018-06-25 insert changes
    [DLP__module insert v2_fixed.stl, module insert v2.stl, module insert v2_fixed.stl]
2018-06-25 Insert work
    [module insert v2.stl, module insert v2_fixed.stl]
2018-06-29 fixed arduino code to send proper values to osd
2018-06-30 case work
    [PCB 1d.brd, case.stl, case_fixed.stl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]
2018-06-30 slicer files
    [side.stl, side_fixed.stl, side_left.stl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]
2018-07-01 case modification
2018-07-01 case v2
    [case.stl, case2.stl, case2_fixed.stl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]
2018-07-01 3D work
    [side_left.stl, side_left_fixed.stl, side_right.stl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]
2018-07-04 PCB and Case changes
    [DVR adapter.stl, DVR adapter_fixed.stl, PCB 1d.brd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]
2018-07-05 Updates
    • 3D work
    • Cleaning up
    [DVR adapter.stl, DVR adapter_fixed.stl, __case2_fixed.stl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]
2018-07-06 Small PCB change
    [DVR adapter.stl, DVR adapter_fixed.stl, PCB 2d.brd]
2018-07-12 Case work and tiny PCB changes
    [DVR adapter.stl, DVR adapter_fixed.stl, PCB 1d.brd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]
2018-07-12 cleaning up
    [module insert v3.stl, module insert v3_fixed.stl]
2018-07-13 new defults for voltage reading and warning beeper synct with LED
2018-07-18 Adding Case cover and a cable junction box
    [case-cover plate.dxf, cover_cable_fixed.stl]
2018-07-18 More cleanup
    [C3.csv, C3.xlsx, Module-PCB.brd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]
2018-07-18 Case photos
2018-07-19 Update Battery Icon
2018-08-02 Alternative 3D formats
    [case3.dxf, module insert v3.dxf, side left.dxf]
2018-10-27 Remove old gerber files
2018-10-28 removed switch from concept drawing
2018-11-01 TrueD (dockking firmware) support
    • AutoDVR (start/stopp based on RSSI values)
    • Alternative layout for the main screen with RSSI, band & channel data
2018-11-01 enable the low voltage buzzer again
    [ARDUINO-Code.ino]
2018-11-08 voltage detection changes
2018-11-14 Scaled 3D files & added a magnet stand
    [CE3_Case_scaled_fixed.stl, CE3_DVR adapter_scaled_fixed.stl, CE3_Side_left_scaled_fixed.stl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]
2018-11-16 STL-file for the coverplate
    [case cover plate_fixed.stl]
2018-11-16 added a thicker version
    [case cover plate 1,0mm_fixed.stl, case cover plate 1,5mm_fixed.stl]
2018-11-29 Updated PCBs
    • Round edges
    • Covered vias on PCB1
    • OLED pin swap (VCC <> GND) on PCB2
    [PCB 1c.brd, PCB 1c.sch, PCB 1d.brd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]
2018-12-27 New PCB revision (added a cap)
    [PCB 1d.brd, PCB 1d.sch, PCB 2d.brd]
2019-01-23 Experimental OSD Addon-PCB
    [MINIM_PCB.brd, MINIM_PCB.sch]
2019-02-12 Experimental PCBs
    [PCB 1e.brd, PCB 1e.sch, TEST_PCB.brd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]
2019-07-08 new pcb1 revision 3 (5v on RJ45 and OSD PCB footprint added)
    [MINIM_PCB.brd, MINIM_PCB.sch, PCB 1e.brd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]
2019-07-08 added 75ohm resistor to pcb
    [PCB 1e.brd, PCB 1e.sch]

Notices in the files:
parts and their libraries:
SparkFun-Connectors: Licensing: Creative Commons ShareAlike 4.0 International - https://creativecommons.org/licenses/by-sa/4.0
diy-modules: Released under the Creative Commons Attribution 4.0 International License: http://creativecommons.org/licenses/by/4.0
